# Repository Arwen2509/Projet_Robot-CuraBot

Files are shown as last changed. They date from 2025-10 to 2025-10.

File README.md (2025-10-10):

Le projet de ma première année en école d'ingénieur consistait à créer un robot autonome, donc capable d'effectuer certaines tâches seul.
Nous devions d'abord trouver un sujet, puis une problématique, et enfin nous renseigner sur les solutions existantes afin de produire la nôtre.
Ainsi l'idée nous est venue de proposer un robot autonome capable de se déplacer seul dans un hôpital pour livrer des médicaments directement aux patients dans leurs chambres.

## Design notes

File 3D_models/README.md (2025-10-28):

# 3D Models

This folder contains all 3D models for the CuraBot project.

## Description
The 3D models in this folder are used for the robot components and can be printed using a 3D printer.

## Usage
These files are ready to be used for manufacturing and assembly of the CuraBot.

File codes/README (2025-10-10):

Notre robot fonctionne à l'aide de 2 cartes Arduino, et donc de 2 codes.
Les cartes communiquent en I2C, une première permet de gérer l'écran d'affichage (maître), et la deuxième contrôle tous les autres composants, moteurs, capteurs... (esclave).

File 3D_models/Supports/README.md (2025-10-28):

# Supports

This folder contains the 3D models for support components and accessories of the CuraBot.

## Contents

The files in this directory include:
- Sensor mounts and holders
- Crazy wwheel support
## File Format

All 3D models are provided in 3mf format for 3D printing.

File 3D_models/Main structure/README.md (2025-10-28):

# Main Structure

This folder contains the 3D models for the main structural components of the CuraBot.

## Contents

The files in this directory include:
- Main chassis and frame components
- Structural support pieces
- Base plates and mounting brackets
- Core mechanical assemblies

## File Format

All 3D models are provided in STL format for 3D printing.

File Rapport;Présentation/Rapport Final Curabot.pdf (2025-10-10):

Rapport final de projet : CuraBot, le livreur de médicament

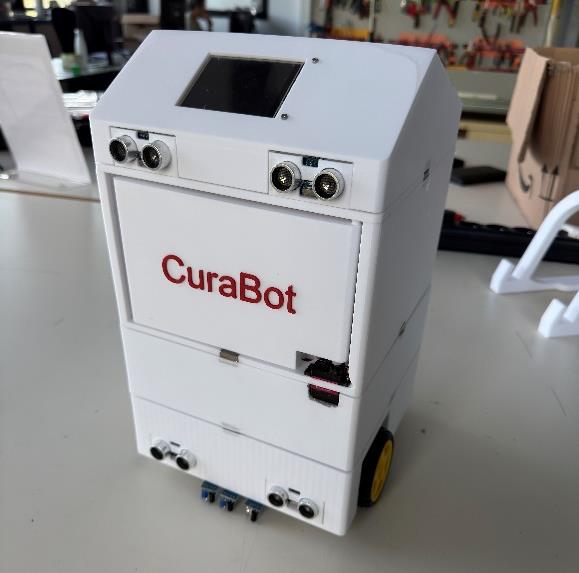
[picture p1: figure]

Table des matières

I. Introduction

Dans l’objectif de l'amélioration continue des soins hospitaliers, la gestion des tâches logistiques constitue un défi important pour les équipes soignantes, en particulier les infirmiers. Ceux-ci sont souvent confrontés à une charge de travail élevée, combinant soins aux patients, gestion des traitements et activités annexes comme la distribution de médicaments. Ce cumul de tâches, bien que nécessaire, peut entraîner une surcharge cognitive et physique, affectant la qualité des soins prodigués et le bien-être des professionnels de santé.

Ce robot a été réalisé dans le cadre du projet pédagogique de troisième année de Robotique. CuraBot est le résultat d’un travail commun en binôme, se reposant sur une répartition des tâches efficaces : la partie programmation et électronique d’une part, la conception structurelle et l’assemblage du robot de l’autre. Ce rapport met en lumière les choix techniques, les contraintes rencontrées et les solutions mises en œuvre pour le bon fonctionnement du robot.

L’objectif principal de CuraBot est de soulager le personnel hospitalier. Il doit apporter les médicaments aux patients de chambres différentes en suivant une ligne tracée au sol. Il est conçu pour qu’il soit modulaire : on doit pouvoir rajouter des baies à médicaments suivant les besoins de l’hôpital.

II. Schéma Electrique

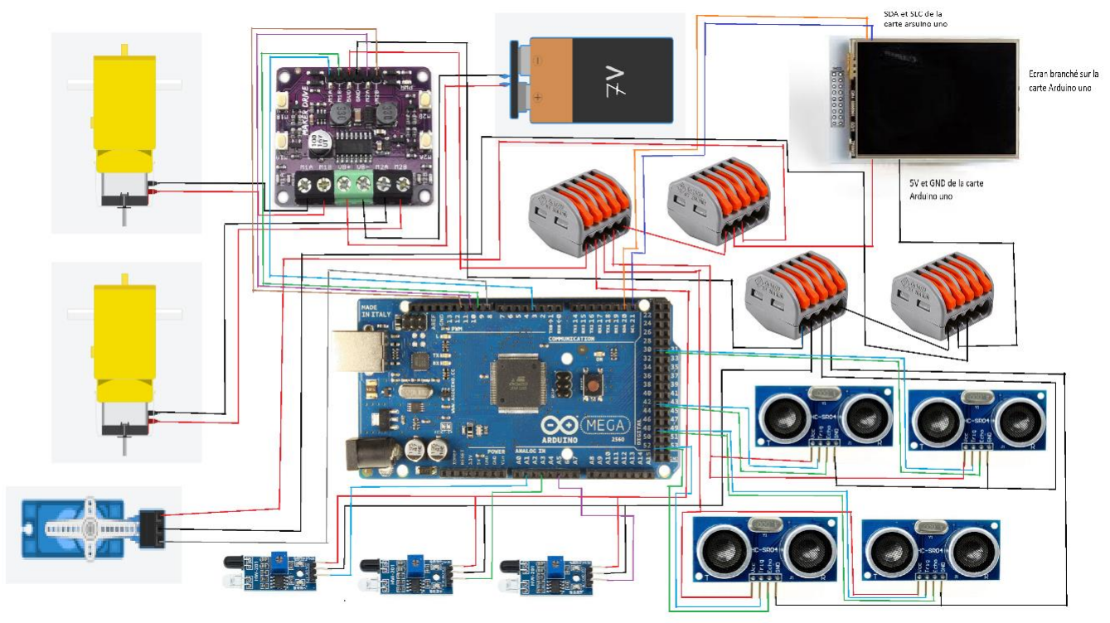
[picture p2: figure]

III. Algorithme de fonctionnement

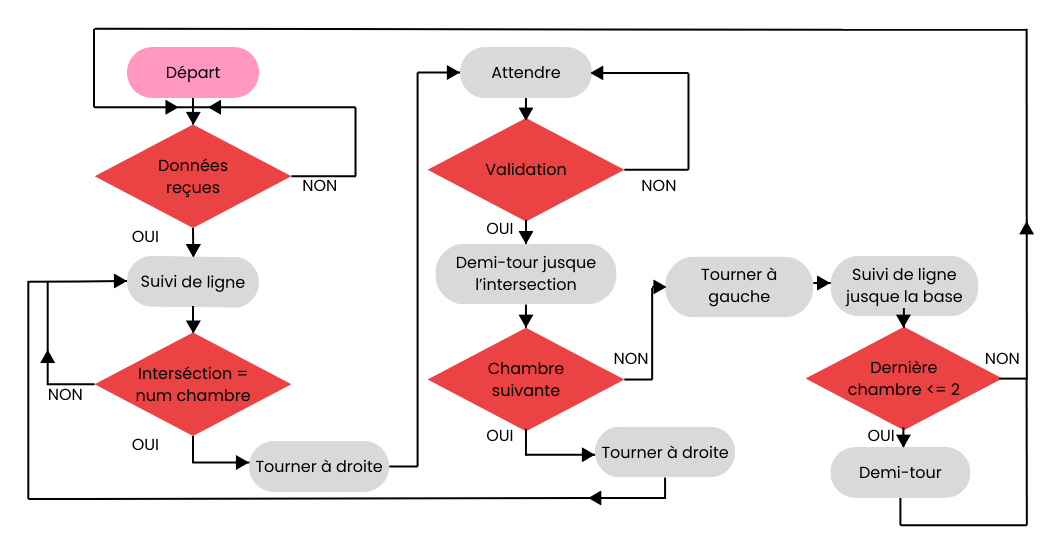
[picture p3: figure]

Pour la programmation on retrouve 3 parties principales :

Écran + Communication I2C:

L’écran sert d’interface homme-machine, il est donc programmé pour avoir une interface claire et simple d’utilisation permettant de choisir la liste des chambres que doit livrer le robot. Une fois cette liste sélectionnée l’information doit aller de l’écran connecté sur l’Arduino Uno jusqu'à la carte Arduino Mega contrôlant les moteurs et différents capteurs. Le code comporte donc une partie pour gérer la communication I2C entre les deux cartes.

Suivi de ligne :

La carte Arduino Mega est programmée pour lancer le robot une fois que celle-ci reçoit l’information provenant de l’écran. Le robot doit suivre la ligne noire jusqu’à atteindre la chambre qu’il doit livrer. Pour cela, la carte est programmée pour contrôler les moteurs en fonction des données reçues par les capteurs infrarouges. De plus pour savoir si le robot a atteint la bonne chambre ou non il compte les intersections (quand les trois capteurs IR captent la ligne).

Contrôle porte :

Une fois arrivé dans la bonne chambre, le robot ouvre la porte et attend une validation provenant de l’écran. Cette partie de code se base encore une fois sur la communication I2C entre les deux cartes pour que le robot ferme la porte une fois la validation effectuée sur l’écran.

Ensuite, le robot sort de la chambre et va à la suivante ou bien retourne à sa base de départ.

IV. | Coûts du projet
Inventaire | Nombre/Quantité Prix unitaire | | Coût total par produit
Capteur Ultra-Son | 4 | 3,49 | 13,96
3 Capteur Infra-Rouge | 1 | 6,99 | 6,99
Arduino Mega | 1 | 30,04 | 30,04
Arduino Uno | 2 | 9,99 | 19,98
Ecran LCD | 1 | 24,99 | 24,99
Servomoteur | 1 | 3,50 | 3,50
Moteur DC | 2 | 2,00 | 4,00
2 Roues | 1 | 6,39 | 6,39
Roue folle | 1 | 2,25 | 2,25
Interrupteur | 1 | 0,98 | 0,98
Batterie 7,4V | 1 | 16,98 | 16,98
Contrôleur Cytron | 1 | 5,11 | 5,11
Boîtes de 120 câbles Dupont | 1 | 8,99 | 8,99
Bobine PETG | 2 | 19,99 | 39,98
| | Total coût matériel | 184,13
Etudiant | Nombre d'heures de cours | Nombre d'heures supp | Taux horaire Brut | Coût humain
Arwen | 80 | 150 | 20,88 | 4802,4
Alexis | 80 | 210 | 20,88 | 6055,2
| | | Total | 10857,6
Total matériel | 184,13
Total humain | 10857,6
Coût Total | 11041,73
V. Ajustements bibliographie

Lors de la phase de conception initiale, nous avions envisagé d’intégrer à CuraBot un système de contrôle à distance par Bluetooth via une application mobile conçue avec AppInventor, ainsi qu’un système de localisation par lecture de QR codes placés devant les chambres. Le Bluetooth permettait théoriquement de sélectionner les chambres à livrer sans interface embarquée, tandis que les QR codes devaient permettre au robot de reconnaître précisément l’endroit où il se trouvait afin de s’arrêter devant la bonne chambre.

Cependant, ces choix ont été abandonnés au cours de l’évolution du projet. Le contrôle Bluetooth, bien que fonctionnel dans un cadre simple, s’est révélé peu robuste et peu intuitif en environnement réel. Il nécessitait une connexion stable, une application tierce à maintenir, allongeait inutilement le temps de configuration et aurait interféré avec. L’intégration d’un écran tactile s’est finalement révélée plus ergonomique, en réunissant en un seul dispositif l’affichage et la saisie des informations.

Concernant les QR codes, la reconnaissance s’est avérée plus complexe à mettre en œuvre que prévu, notamment en raison des contraintes de positionnement, de luminosité, et du traitement d’image requis. Nous avons donc choisi de nous orienter vers un système plus simple et plus robuste basé uniquement sur le suivi de ligne combiné à des repères d’intersection, assurant une meilleure régularité de fonctionnement et facilitant les tests.

VI. Problématiques surmontées
Le robot était initialement prévu pour rouler grâce à 2 roues motrices sur les deux côtés au milieu et 2 roues folles positionnées sur l’avant et l’arrière. Or ce système ne rendait finalement pas stable CuraBot. Il a donc été choisi d’enlever une roue folle pour passer sur un système de trois supports en forme de triangle : les deux roues motrices dans les coins avant et la roue folle au centre à l’arrière.

VII. Conclusion et perspective
Ce rapport bibliographique nous a permis d’explorer les différentes approches techniques envisageables pour la conception d’un robot livreur de médicaments, en confrontant nos idées initiales aux contraintes réelles de mise en œuvre. Au fil de nos recherches, nous avons pu affiner notre cahier des charges, identifier les solutions les plus adaptées à notre contexte, et proposer une première version de CuraBot reposant sur un système de suivi de ligne, à la fois simple, économique et fiable.

Nos choix ont été guidés par le souci de faisabilité dans le cadre d’un premier prototype, avec une priorité donnée à la stabilité, la modularité mécanique, et la cohérence fonctionnelle. Certains dispositifs initialement envisagés, comme le contrôle Bluetooth ou la lecture de QR codes, ont été écartés en faveur de solutions plus robustes et ergonomiques, comme l’intégration d’un écran tactile et d’un système de repérage par trajectoire prédéfinie.

Dans la continuité du projet, nous souhaitons faire évoluer CuraBot vers une version plus autonome et intelligente. Pour cela, l’objectif principal de l’année prochaine est de remplacer le système de suivi de ligne par une navigation basée sur la cartographie 3D de l’environnement, rendue possible grâce à l’intégration d’un capteur LiDAR.

Cette technologie permettra à CuraBot :

- De construire une carte de son environnement en temps réel (SLAM),
- De naviguer librement dans des couloirs sans balisage au sol,
- D’éviter dynamiquement les obstacles même imprévus (chariots, personnes),
- Et d’atteindre une flexibilité d’usage bien plus proche des standards industriels des robots hospitaliers actuels.

Cette prochaine étape nécessitera une refonte partielle de l’architecture logicielle du robot, un traitement de données plus complexe, ainsi qu’une amélioration de la capacité de calcul embarquée. Elle représente un véritable défi technique, mais aussi une opportunité d’approfondir nos compétences en robotique mobile, en intelligence embarquée et en algorithmique de navigation.

En résumé, ce projet nous a permis de poser des bases solides sur le plan technique et organisationnel, que nous comptons enrichir l’année prochaine pour franchir une nouvelle étape vers un robot plus autonome, intelligent et adapté aux besoins réels des hôpitaux modernes.

VIII. Bibliographie
Liens matériels :

120 Câbles Dupont (https://www.amazon.fr/AZDelivery-Jumper-Cavalier-C%C3%A2ble-Arduino/dp/B074P726ZR) - Bobine PETG (https://www.amazon.fr/eSUN-Pr%C3%A9cision-Dimensionnelle-Cartouche-Imprimante/dp/B07FXGXFH3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) -Controleur Cytron (https://eu.robotshop.com/fr/products/controleur-moteur-h-bridge-pour-debutant-maker-drive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) - Batterie 7,4V (https://www.amazon.fr/Batteries-Rechargeables-connecteur-l%C3%A9lectronique-%C3%A9quipement/dp/B0BQGSKGTK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) - Interrupteur (https://www.amazon.fr/GTIWUNG-Interrupteur-Commutateur-poussoir-appareils/dp/B08CY5437N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) - Roue Folle (https://www.amazon.fr/Roulettes-Demenagement-Pivotantes-Auto-adh%C3%A9sives-Universelles/dp/B0DQYFWRXQ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) - 2 Roues (https://www.amazon.fr/Baosity-Intelligent-Voitures-Arduino-Bricolage/dp/B07QL3CDTW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) - Moteur DC (https://www.amazon.fr/Vitesses-Engrenages-Voiture-Intelligent-Arduino/dp/B096ZH5WQ6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) - Servomoteur (https://www.amazon.fr/Binghe-Servomoteur-Rotation-h%C3%A9licopt%C3%A8re-Compatible/dp/B0DFCGD34B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) - Ecran LCD Tactile (https://www.amazon.fr/ELEGOO-Tactile-320x240-Technical-Arduino/dp/B01JD4TJZU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) - Arduino Uno (https://www.amazon.fr/ElectroWorldFR-Controller-ATmega328P-Microcontr%C3%B4leur-Compatible/dp/B0BVGW4SC8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) - Arduino Mega (https://www.amazon.fr/Retoo-Atmega-Microcontr%C3%B4leur-Board-microcontr%C3%B4leur/dp/B0BY8R9Y7N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) - 3 Capteurs Infra-Rouge (https://www.amazon.fr/AZDelivery-infrarouge-kollissions-d%C3%A9tection-obstacles/dp/B07D924JHT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) - Capteur Ultra Son (https://www.amazon.fr/OcioDual-Ultrasons-T%C3%A9l%C3%A9m%C3%A8tre-Ultrasonique-Raspberry/dp/B075MDMDL2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)

Liens aide au développement :

https://www.aranacorp.com/fr/utilisation-dun-shield-tft-lcd-avec-arduino/

https://circuitdigest.com/microcontroller-projects/arduino-i2c-tutorial-communication-between-two-arduino (https://circuitdigest.com/microcontroller-projects/arduino-i2c-tutorial-communication-between-two-arduino)

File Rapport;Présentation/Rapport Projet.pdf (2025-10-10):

# RAPPORT BIBLIOGRAPHIQUE

## Année scolaire 2024-2025

# "CuraBot, le livreur de médicament"

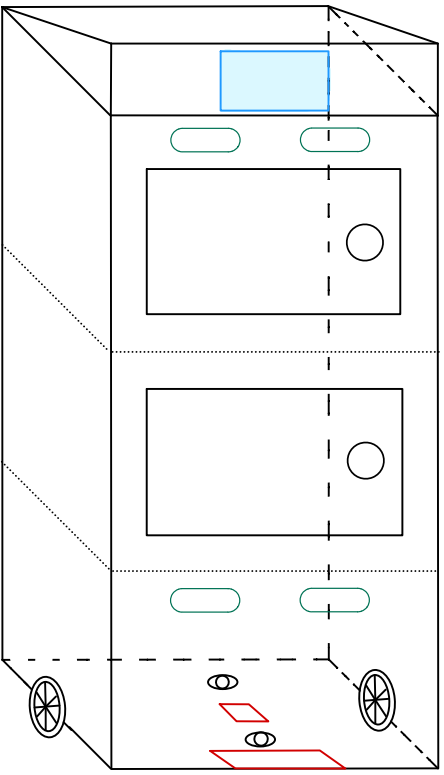
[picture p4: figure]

# Etudiants : Arwen Fracassi, Alexis Xueref Encadrant : Pascal Masson

Ecole Polytechnique Universitaire de Nice Sophia-Antipolis, Robotique Systèmes Autonomes930 route des Colles, Parc de Sophia Antipolis, 06410 BIOT

Université Cote d’Azur

## Sommaire

# Introduction

Dans l’objectif de l'amélioration continue des soins hospitaliers, la gestion des tâches logistiques constitue un défi important pour les équipes soignantes, en particulier les infirmiers. Ceux-ci sont souvent confrontés à une charge de travail élevée [1], combinant soins aux patients, gestion des traitements et activités annexes comme la distribution de médicaments. Ce cumul de tâches, bien que nécessaire, peut entraîner une surcharge cognitive et physique, affectant la qualité des soins prodigués et le bien-être des professionnels de santé.

Face à ces enjeux, l’automatisation des tâches répétitives et non directement liées aux soins, telle que la livraison des médicaments, apparaît comme une solution innovante pour alléger la charge de travail des infirmiers. C’est dans cette optique que l’idée d’un robot livreur de médicaments au sein des hôpitaux a émergé. En développant un système robotisé capable de transporter et distribuer les médicaments aux différents services, il serait possible de libérer du temps pour les infirmiers [2], leur permettant ainsi de se concentrer sur leurs fonctions principales : l'accompagnement et les soins des patients.

Ce rapport bibliographique a pour objectif d’explorer les différentes technologies existantes dans le domaine de la robotique hospitalière, d’analyser les systèmes similaires déjà en place et d’évaluer leur pertinence pour la conception d’un robot livreur de médicaments à tous les niveaux de conception du robot.

# Chapitre I : Présentation générale du robot

Les robots de livraison de médicaments se répartissent majoritairement en deux types : ceux qui se déplacent de manière autonome en s'adaptant à l'environnement de l'hôpital, et ceux qui suivent des parcours prédéfinis, comme des lignes tracées au sol.
Même si les robots autonomes, avec leurs capteurs comme le LIDAR ou des caméras, semblent plus flexibles puisqu'ils peuvent réagir aux changements autour d’eux, ils présentent des inconvénients. Ils sont plus chers à fabriquer, leur entretien est plus complexe, et ils demandent une infrastructure technologique plus poussée. Dans un hôpital, où les itinéraires sont souvent réguliers et prévisibles, cette flexibilité n’est pas aussi critique. Notre plus grande inspiration étant le REEMAN Drug Delivery [3] utilisant ce système. Il représentait la vision du robot livreur que l’on avait. Or nous avons décidé de ne pas partir sur la cartographie car c’est une technique plus complexe et demandant en ressources.
C’est pourquoi, pour une solution plus simple et efficace, nous allons privilégier les robots suiveurs de ligne [4]. Ces robots utilisent des capteurs optiques pour suivre une ligne tracée au sol, ce qui permet de naviguer précisément avec un système facile à installer et à maintenir. En plus, ce type de robot coûte moins cher que les modèles autonomes, et les tracés au sol peuvent être rapidement ajustés si jamais il faut changer un itinéraire, ce qui offre quand même une bonne flexibilité pour les besoins de l’hôpital.
Nous prévoyons aussi de rendre notre CuraBot modulaire, en offrant la possibilité d’augmenter la capacité de livraison, améliorant ainsi l'efficacité en réduisant le nombre de trajets nécessaires. Mais aussi de proposer une flexibilité aux hôpitaux d’adapter le robot à des besoins variables en permettant une réduction des coûts.
En résumé, CuraBot, le robot modulaire suiveur de ligne est une solution pratique, économique, et bien adaptée afin de gérer la logistique dans un hôpital.

# Chapitre II : Design

## II.1. Cahier des charges

Nous souhaitons que le robot soit modulaire, donc qu’il permette d’ajouter ou de retirer des étages facilement, sans nécessiter d’outils complexes. Chaque étage doit pouvoir transporter un certain nombre de médicaments dans des compartiments sécurisés. CuraBot doit pouvoir suivre des lignes tracées au sol via des capteurs adaptés, même avec plusieurs étages ajoutés.

## II. 2. Structures envisagées

### II. 2. 1. Le robot pilule

Initialement, nous avons imaginé de modéliser notre robot en forme de pilule de médicament comme le montre la Figure 1. Afin de faire un rappel avec l’objet de nos livraisons. Cependant, nous nous sommes heurtés rapidement avec des contraintes techniques qui auraient empêché de positionner les roues sur la face du bas aisément, notamment les roues folles, qui permettent la stabilisation du robot. De plus, l’intégration des capteurs sur la surface arrondie peut compliquer leur orientation et la précision de leurs mesures. La fabrication et l’assemblage d’une forme arrondie est plus complexe qu’une forme avec des bords plats.

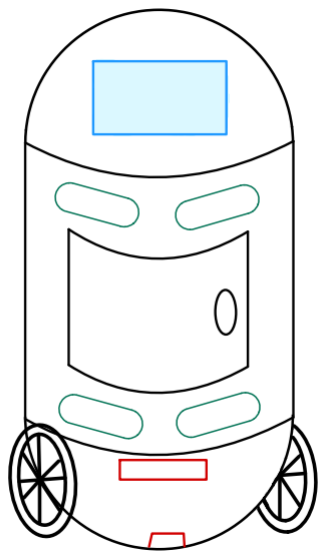
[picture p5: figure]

Figure 1 : Schéma du robot pilule

### II. 2. 2. Le REEMAN Drug Delivery Intelligent Robot

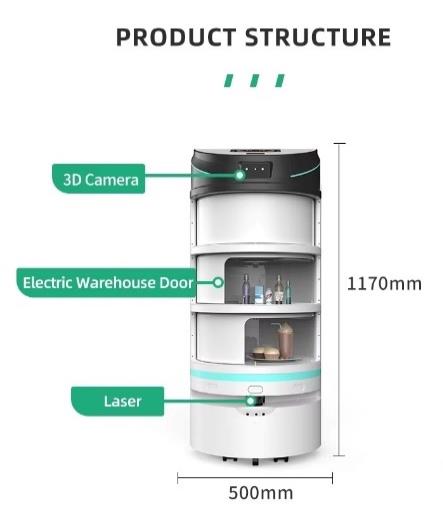
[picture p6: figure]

Notre étude s’est portée par la suite sur Le
REEMAN Drug Delivery Intelligent Robot [3] (figure 2) dont la forme était toujours arrondie mais avait une surface plane au niveau de la base afin de pouvoir disposer les roues et capteurs suiveur de lignes facilement et proche du sol. Néanmoins, ce robot n’utilise pas un système de suivi de ligne mais un système de caméra et laser, ce qui n’est pas dans la ligne directrice de notre robot. De surcroît, nous cherchons à ce que l’ouverture des portes se fasse de façon battante et pas coulissante, ce qui n’est pas prévu par ce robot. La forme arrondie n’est pas optimale pour l’installation des capteurs d’obstacle et pour la fabrication du robot. Enfin, ce robot n’est pas modulaire, on ne peut pas choisir d’enlever ou de rajouter des étages.

## II. 3. Structure retenue

À la suite de nos recherches, nous avons décidé de partir sur un robot en forme de parallélépipède rectangle. En effet cette forme va nous permettre de pouvoir facilement positionner les roues et calibrer les capteurs nécessaires au suivi de ligne et de détection d’obstacle comme le montre la figure 3. D’autre part, avoir des faces planes nous permet d’avoir une ouverture pour les portes de type battante sans gênes au niveau du pivot.
Concernant la partie modulaire, notre choix s’est porté sur le fait de séparer en blocs notre robot. En effet, nous l’avons découpé en 3 modules différents :
- Le module Motorisation : Ce module va être composé de toute la partie basse du robot. On va y retrouver les différentes roues, les moteurs pour faire tourner les roues, les capteurs de suivi de lignes, le capteur de QR-code, les cartes électroniques qui feront fonctionner le robot et toute l’électronique qui permettra de se relier aux autres blocs. Il sera le plus lourd car la plus grande partie des composants y sera mais aussi pour s’assurer que la structure ne bascule pas lors de déplacements.
- Le module Interface : Ce module est celui qui rend possible l’interaction Homme-Machine. En effet, ce sera sur ce module que nous allons retrouver l’écran qui offrira la possibilité de choisir le trajet du robot. On retrouvera aussi deux capteurs à obstacles, qui servent à détecter les obstacles en hauteur. Mais aussi, un compartiment de livraison de médicament, où un moteur permettant de contrôler la porte sera présent.

Figure 2 : Le REEMAN Drug Delivery Intelligent Robot

- Le module Médicament : Ce module est celui qui offrira la possibilité d’augmenter la capacité du robot. En effet, seul ce module peut être rajouté et ne comporte aucuns composants essentiels au fonctionnement du robot. On y retrouvera seulement la baie à médicaments et le moteur permettant d’ouvrir et de refermer la porte.

Le robot doit avoir obligatoirement le module Motorisation et Interface pour fonctionner correctement, il ne pourra pas faire sans. C’est pour cela que nous avons choisi d’inclure une baie à médicaments dans le module Interface. Les modules seront tous modélisées de façon qu’ils s’emboîtent entre eux avec des zones de fixations à vis pour être sûr qu’ils ne se désolidarisent pas du robot. La partie du fond du robot sera creuse afin de faire passer tous les câbles plus facilement.

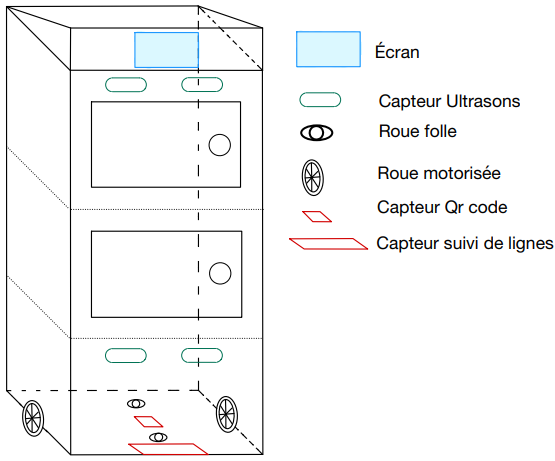
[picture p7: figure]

Figure 3 : Schéma de CuraBot

# Chapitre III : Déplacements et repères

## III.1. Cahier des charges

Notre robot doit livrer des médicaments à des endroits précis, pour cela il doit être capable de se déplacer et se repérer correctement dans son environnement, tout en étant capable de s’arrêter aux endroits indiqués.

## III. 2. Déplacement dans l’environnement

Le robot peut se déplacer dans un certain lieu de différentes manières, il peut soit connaitre le lieu par cartographie, soit savoir où il doit se rendre en suivant une ligne par exemple.
Dans la première option on retrouve la cartographie [5] par laser, présente dans certains aspirateurs robots qui leur permet de détecter des obstacles et de connaitre la distance à laquelle ils se trouvent afin de faire une carte de la pièce. Cependant cela nécessite que le robot se déplace dans tout son environnement une première fois juste pour le découvrir.
Il existe aussi la cartographie par camera, mais cette solution est bien plus couteuse et plus complexe.
C’est pourquoi nous avons décidé de nous tourner vers un robot suiveur de ligne [4], celui-ci étant plus simple à réaliser et tout aussi efficace dans notre cas. Le robot connait précisément son trajet plutôt que l’entièreté de son environnement, et il en va de même pour le personnel qui peut donc prévoir comment va se déplacer le robot.

## III. 3. Arrêts

Le robot doit être capable de s’arrêter au bon endroit, il doit s’arrêter aux chambres indiquées afin d’y livrer les médicaments. Pour cela nous avons parcouru plusieurs possibilités. La première consistait à utiliser le nombre d’intersections rencontrées par le robot pour qu’il “connaisse” le numéro des chambres à sa gauche et à sa droite et qu’il choisisse son chemin en fonction.

Mais nous avons finalement opté pour un scan de QR code (cf annexe 1). Les QR codes seront disposés sur le trajet du robot face à la chambre correspondante comme le montre la figure 4, le robot pourra donc suivre son trajet tout en les scannant et ainsi s’arrêter lorsqu’il se trouvera devant la bonne chambre. Afin d’accéder à la chambre le robot devra aussi attendre que la porte soit bien ouverte.

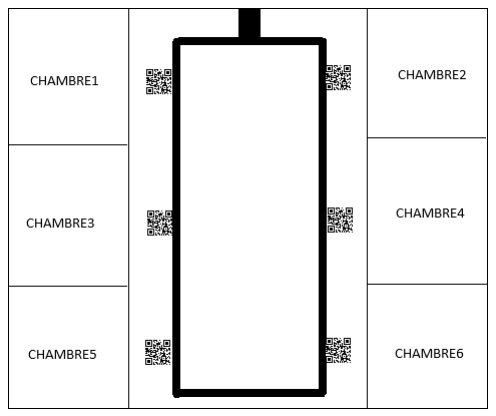
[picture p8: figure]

Figure 4 : Chemin du CuraBot

## III. 4. Roues

Nous nous sommes ensuite intéressés au choix des roues. On s’est d’abord penchés sur les roues des aspirateurs robots Roomba [6] car celles-ci sont proches du sol comme notre robot. Ces roues permettent au robot de passer sur certains obstacles au sol comme les tapis. Pour notre projet, le robot circule dans un hôpital, et donc il ne devrait pas rencontrer d’obstacles de ce genre, ce type de roue n’est donc pas nécessaire.
Nous nous sommes ensuite renseignés sur les roues Omniwheel [7], celles-ci permettent au robot de tourner dans toutes les directions. De même que pour les roues de Roomba cela n’est pas nécessaire dans notre cas.
Finalement l’utilisation de deux roues simples (cf annexe 1) motorisées ainsi que deux roues folles (cf annexe 1) nous a parue être la meilleure option. Les deux roues motorisées sur les côtés du robot lui permettront de tourner afin de suivre correctement son trajet, et les roues folles permettrons de rajouter de l’équilibre au robot.

# Chapitre IV : Motorisation

## IV. 1. Cahier des charges

Le robot doit être capable d’avancer en supportant sa propre masse et celles des médicaments. Il doit aussi pouvoir tourner sur lui-même et pouvoir ouvrir et refermer les portes des baies à médicaments.

## IV. 2. Motorisation des roues

Afin de répondre aux exigences du cahier des charges, nous avons décidé de partir sur deux moteurs avec encodeur et un contrôleur. En effet, cette configuration va nous permettre de contrôler chaque roue du robot.
Les moteurs de 6V, choisis pour leur efficacité énergétique, offrent une puissance suffisante pour propulser le robot et transporter une charge légère à modérée, comme celle des médicaments. Ces moteurs, tout en étant peu gourmands en énergie, sont capables de fournir la force nécessaire pour déplacer le robot de manière fluide, même lorsqu’il est chargé. Cela garantit que le robot pourra avancer sans difficulté, supportant à la fois son propre poids et celui de sa cargaison.
Le contrôleur Cytron, associé à cette configuration, permet de réguler précisément la vitesse et la direction des roues. Grâce à la modulation de largeur d’impulsion (PWM), il est possible d'ajuster le fonctionnement de chaque moteur indépendamment, ce qui permet au robot de réaliser des manœuvres complexes telles que des virages serrés ou des rotations sur place. La capacité de tourner sur lui-même est ainsi assurée par la possibilité de contrôler individuellement chaque roue. En faisant tourner les roues dans des directions opposées, le robot peut pivoter sur lui-même, répondant ainsi à cette exigence du cahier des charges. L’intégration d’encodeurs sur les moteurs Cytron apporte un avantage supplémentaire en termes de contrôle. Les encodeurs permettent de mesurer avec précision la rotation des roues, offrant un retour d’information en temps réel sur la position et la vitesse. Cela permet de corriger les déviations éventuelles, assurant ainsi que le robot suit sa trajectoire avec précision, même en cas de changements de charge ou de surface. Ce retour d'information est essentiel pour maintenir un suivi optimal de la ligne tracée au sol et garantir que le robot reste sur sa route prévue.
Ainsi, la solution proposée, avec deux moteurs de 6V et un contrôleur Cytron, répond pleinement aux critères du cahier des charges en assurant que le robot peut avancer tout en supportant sa charge et effectuer des rotations sur lui-même, tout en restant fiable et économe en énergie. (cf annexe 1 pour toutes les pièces)

## IV. 3. Motorisation des portes

Afin de contrôler l’ouverture des portes, nous nous sommes retrouvés face à la problématique de pouvoir ouvrir la porte manuellement et que CuraBot prenne en compte cette ouverture afin qu’il adapte la rotation nécessaire pour la fermeture.
Le servomoteur paraît être le meilleur choix car il offre la possibilité de suivre la position de la porte et même d’ajuster sa position par la suite. Mais, un servomoteur standard peut être gênant pour une ouverture manuelle, car il impose sa position. Cependant, il existe des servomoteurs avec retour de position ou des mécanismes d’embrayage qui désengagent le moteur quand la porte est ouverte manuellement (cf annexe 1).

# Chapitre V : Capteurs

## V.1. Cahier des charges

Dans notre projet nous avons besoin de capteurs pour deux raisons principales, d’abord pour permettre au robot d’effectuer le suivi de ligne, et ensuite pour détecter des obstacles potentiels sur son chemin.

## V.2. Suivi de ligne

Pour se déplacer, le robot devra suivre une ligne noire au sol, pour cela nous allons utiliser trois capteurs infrarouges disposés de la même façon que sur la figure 5 (cf annexe 1).

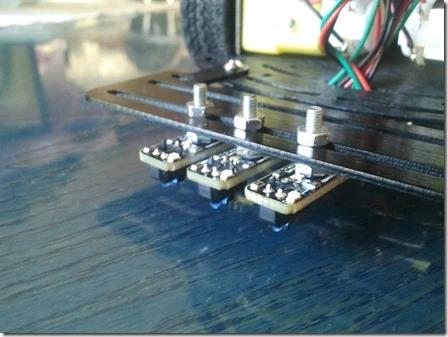
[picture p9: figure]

Figure 5 : Capteurs suivi de lignes

Les trois capteurs permettront au robot de savoir s'il est sur le bonne trajectoire ou non. Le capteur du milieu est sensé rester au-dessus de la ligne noire et donc ce capteur ne doit pas recevoir de lumière, contrairement aux deux capteurs sur les côtes. De ce fait, si l’un des deux autres capteurs ne reçoit plus la lumière, cela signifie que le robot doit modifier sa trajectoire.

## V.3. Détecter les obstacles

Comme nous nous sommes intéressés au fonctionnement des robots aspirateur nous avons aussi observé les capteurs qu’ils utilisaient.
Certains modèles utilisent des capteurs de contact afin de changer de direction lorsqu’ils touchent un obstacle. Cependant ce type de capteurs ne correspond pas à notre projet, on veut que le robot détecte les obstacles pour s’arrêter avant de les atteindre, et les contourner si nécessaire.

On retrouve aussi l’utilisation du lidar [8], celui-ci utilise des lasers infrarouges afin de détecter tous les obstacles autour de lui et mesurer à quelles distances ils se trouvent. Bien que ce système fonctionne très bien et permette d’obtenir beaucoup de données, la plupart ne nous seront pas utiles, l’utilisation de ce capteur n’est donc pas nécessaire.

Ensuite, la détection d’obstacle est aussi possible grâce à des capteurs infrarouge, cependant le laser risque de passer au travers de surfaces vitrés et donc ne pas renvoyer les bonnes informations au robot.

Finalement, nous avons décidé d’utiliser des capteurs à ultrason (cf annexe 1), étant simples à utiliser et permettant de détecter des obstacles à une distance raisonnable. Ainsi lorsque le capteur détecte un obstacle le robot doit s’arrêter, et si l’obstacle est toujours présent ou bout d’un certain temps celui-ci devra le contourner.

# Chapitre VI : Interface Homme-Robot

## VI.1. Cahier des charges

Dans notre cas, le robot doit interagir avec l’utilisateur, afin de savoir à quelles chambres il doit se rendre. Mais celui-ci pourra aussi afficher des informations pour les autres membres du personnel qu’il pourrait croiser ainsi que pour les patients.

## VI.2. Solutions étudiées

Pour sélectionner les chambres à livrer un Numpad serait suffisant, cependant ce système ne nous permettrait pas d’obtenir d’autres informations, comme un affichage des chambres qu’il va livrer pour vérifier qu’une erreur n’a pas été faite.

Au contraire un simple écran non tactile permettrait l’affichage d’information mais on ne pourrait pas choisir directement les chambres à livrer depuis le robot. Ce type de modèle pourraient convenir s’il était combiné à l’utilisation d’une application mobile permettant de communiquer par Bluetooth avec le robot comme AppInventor MIT. Dans ce cas la communication Bluetooth permettrait de transmettre le numéro des chambres à livrer et l’écran permettrait d’afficher certaines informations.
Il nous parait donc plus simple d’utiliser directement un écran tactile Module d’affichage LCD , il permettrait de réunir les deux fonctions en même temps (cf annexe 1). L’utilisation du fonctionnement en Bluetooth peut toujours être utile pour le contrôler sans avoir à être à côté de lui.

# Chapitre VII : Alimentation et Matériaux

## VII. 1. Alimentation

Voici un récapitulatif de tout ce qui doit être alimenté dans le robot avec leur tension nominale :
- 2 moteurs DC avec encodeur FIT0450 : 6V.
- 1 Servomoteur SG90 : 4,8V ~ 6V.
- 1 Contrôleur Cytron : 7V.
- Écran tactile LCD : 3.3V ~ 5V.
- Carte Arduino Méga : +5V.
- Capteurs

Nous choisissons une batterie 7,4V pour s’assurer que chaque composant ne soit pas sous-alimenté. Nous décidons tout de même d’utiliser un régulateur de tension jusqu’à 6V pour être sûr de ne pas endommager les éléments. Afin de ne pas rendre le robot trop lourd, et ainsi le rendre le plus efficient possible, la batterie devra être petite et légère (cf annexe 1).

## VII. 2. Matériaux

Notre robot ne doit être trop lourd afin que les moteurs puissent supporter son poids. Or, il doit tout de même être assez solide pour qu’il ne vacille pas lors de ses déplacements. C’est pour cela que toute la partie motorisation se situe au niveau du bas, afin que la base soit solide. Pour la structure, nous envisageons en première étape d’utiliser du bois découpé au laser afin de faire des ajustements facilement. Lorsque tous les ajustements et positionnements des pièces seront faits, nous passerons à l’impressions 3D en plastique, afin que le robot soit plus esthétique et qu’il corresponde visuellement à note idée de départ.
Il nous parait donc plus simple d’utiliser directement un écran tactile Module d’affichage LCD série SPI, il permettrait de réunir les deux fonctions en même temps (cf annexe 1). L’utilisation du fonctionnement en Bluetooth peut toujours être utile pour le contrôler sans avoir à être à côté de lui.

# Conclusion

Le robot sera constitué de trois parties, premièrement le module motorisation, comportant l’écran tactile, une première porte motorisée par un servomoteur pour stocker des médicaments et deux capteurs à ultrason pour détecter les éventuels obstacles. Puis le module médicament étant lui constitué d’une simple porte motorisée. Et enfin le module motorisation auquel seront fixées les deux roues motorisées afin que les deux roues folles. Il comportera les moteurs DC alimentant les roues ainsi que la batterie. On y retrouvera aussi deux capteurs ultrason, les capteurs infrarouges pour le suivi de ligne ainsi que le lecteur de QR-code.

# Annexe 1 : Liste des pièces à commander

Matériel | Quantité | Lien
Ecran tactile | 1 | Lien écran tactile (https://fr.aliexpress.com/item/33060806447.html?src=google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)
Capteur ultrason | 4 | Lien capteur ultrason (https://www.amazon.fr/AZDelivery-HC-SR04-Ultrasons-T%C3%A9l%C3%A9m%C3%A8tre-Raspberry/dp/B07TKVPPHF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)
Capteur suivi de ligne | 3 | Lien suivi de ligne (https://fr.aliexpress.com/item/1005006269136211.html?src=google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)
Capteur QR-Code | 1 | Lien QR-Code (https://www.gotronic.fr/art-lecteur-de-qr-code-sen0486-34640.htm)
Module Bluetooth | 1 | Lien module Bluetooth (https://www.amazon.fr/AZDelivery-%C3%89metteur-R%C3%A9cepteur-Bluetooth-Compatible-Raspberry/dp/B0722MD4FY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)
Roue motrice | 2 | Lien roue motrice (https://www.amazon.fr/Baosity-Intelligent-Voitures-Arduino-Bricolage/dp/B07QL3CDTW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)
Roue folle | 2 | Lien roues folles (https://www.amazon.fr/Herenear-Roulettes-pivotantes-Caoutchouc-Capacit%C3%A9/dp/B06XFDBCHT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)
Batterie | 1 | Lien batterie (https://www.amazon.fr/Batteries-Rechargeables-connecteur-l%C3%A9lectronique-%C3%A9quipement/dp/B0BQGSKGTK)
Scotch noir | 1 | Lien scotch noir (https://www.castorama.fr/toile-de-reparation-scotch-ultra-noir-48mm-x-10-m/4064035009540_CAFR.prd)
Moteur roue | 2 | Lien moteur roue (https://www.amazon.fr/gp/aw/d/B096ZHKTLW/?aaxitk=13640b74a7744c27a7ef2f08cfdd1b7a&hsa_cr_id=0)
Servomoteur porte | 1 | Lien Servomoteur (https://www.amazon.fr/Fasizi-servo-engrenages-analogiques-h%C3%A9licopt%C3%A8re/dp/B09Z28X9RL)
Contrôleur Cytron | 1 | Lien contrôleur Cytron (https://www.gotronic.fr/art-shield-moteur-cc-10-a-sh-md10-37252.htm)
Régulateur de tension | 1 | Lien régulateur de tension (https://www.amazon.fr/DollaTek-AMS1117-5-5V-R%C3%A9gulateur-dalimentation-4-75V-12V/dp/B07PPKR4HW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)

# Annexe 2 : Planning de travail

Planning Arwen
Lettre | Tâches | Temps | Dépendance
A | Faire les QR codes et préparer le trajet en scotch | 2h | /
B | Montage des roues sur les moteurs | 2h | N
C | Montage capteur infrarouge et programmation du suivi de ligne | 3h | N
D | Montage lecteur QR-code et programmation lecture QR-codes | 3h | N
E | Montage, programmation capteurs ultrasons | 3h | N
F | Programmation évitement d’obstacle | 3h | /
G | Montage, programmation avec un Numpad | 4h | N
H | Test suivi de ligne et rectification si erreurs | 2h | N, A, B, C
I | Montage moteur, encodeur, contrôleur | 2h | N
K | Montage batterie, régulateur | 2h | N

Planning Alexis
Lettre | Tâches | Temps | Dépendance
L | Modélisation Prototypage | 3h | /
M | Prototypage découpe laser | 3h | M
N | Assemblage prototypage | 3h | N
O | Programmation Application Interface | 3h | /
P | Montage Ecran Interface | 2h | O
Q | Modélisation module Motorisation | 4h | /
R | Modélisation module Interface | 4h | /
S | Modélisation module Médicament | 4h | /
T | Modélisation Portes | 2h | R, S
U | Modélisation emboîtement modules | 2h | R, S, T

# Bibliographie

[6] BUT IROBOT Roue Gauche 4624872 Pour Entretien Des Sols [En ligne] // BUT. -https://www.but.fr/produits/5060359287694/Roue-Gauche-4624872-Pour-Entretien-Des-Sols.html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.
[1] Caducee.net Hôpital en crise : les infirmières réclament un plan d'urgence [En ligne] // Caducee.net. - 7 Août 2024. - https://www.caducee.net/actualite-medicale/16388/hopital-encrise-les-infirmieres-reclament-un-plan-d-urgence.html.
[2] Enora SEGUILLON Philippe LAURENSON VIDÉO. À l’hôpital d’Aix, un robot livreur de médicaments [En ligne] // La Provence. - 4 Août 2023. -https://www.laprovence.com/article/region/3572694153676614/a-l-hopital-d-aix-un-robotlivreur-de-medicaments.
itechnofrance Robot 2WD en tant que suiveur de ligne [En ligne] // itechnofrance. - 14 Mars 2013. - https://itechnofrance.wordpress.com/2013/03/14/robot-2wd-en-tant-que-suiveur-deligne/.
[3] Reeman Reeman Delivery Robot [En ligne] // Reemanrobot. -https://www.reemanrobot.com/news/delivery-robots-for-hospitals-a-new-type-of-s-66891554.html.
Robotique.tech Système de détection des obstacles avec Arduino [En ligne] // Robotique.tech. - 21 Juillet 2020. - https://www.robotique.tech/tutoriel/systeme-de-detectiondes-obstacles-avec-arduino/.
[8] SICK Capteurs LiDAR : définition, technologie, applications et solutions SICK [En ligne] // SICK. - 19 Septembre 2022. - https://www.sick.com/fr/fr/sick-sensor-blog/capteurs-lidardefinition-technologie-applications-et-solutions-sick/w/blog-capteurs-LiDAR/.Taufiq_Sobar Arduino Line Follower Uses a 4x4 Keypad [En ligne] // AutoDesk Instructables. -https://www.instructables.com/Arduino-Line-Follower-Uses-a-4x4-Keypad/.
Weiner Stacy Robots make the rounds [En ligne] // AAMC. - 12 Juillet 2019. -https://www.aamc.org/news/robots-make-rounds.
[4] Wikipédia Robot suiveur de ligne [En ligne] // Wikipédia. - 2 Avril 2024. -https://fr.wikipedia.org/wiki/Robot_suiveur_de_ligne.
[5] Wikipédia Robotic mapping [En ligne] // Wikipédia. - 22 Juillet 2023. -https://en.wikipedia.org/wiki/Robotic_mapping.
[7] Wikipédia Roue omnidirectionnelle [En ligne] // Wikipédia. - 7 Août 2024. - https://en-mwikipediaorg.translate.goog/wiki/Omni_wheel?_x_tr_sl=en&_x_tr_tl=fr&_x_tr_hl=fr&_x_tr_pto=rq. Xukyo Un robot qui détecte et évite les obstacles [En ligne] // aranacorp.com. - 9 Novembre 2018. - https://www.aranacorp.com/fr/un-robot-qui-detecte-et-evite-les-obstacles/.

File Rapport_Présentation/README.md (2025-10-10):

Pour commencer notre projet, il fallait d'abord faire des recherches ainsi qu'un rapport pour expliquer ce que l'on prévoyait de faire.
(cf Rapport Projet)

Puis, à la fin de notre projet, une présentation (cf Présentation finale CuraBot) et un rapport pour conclure sur notre projet 
(cf Rapport final Curabot) étaient demandés.

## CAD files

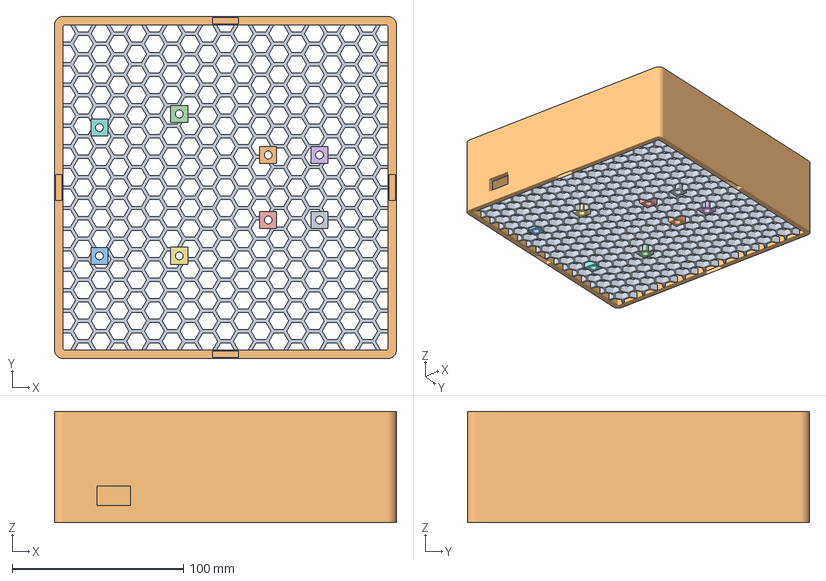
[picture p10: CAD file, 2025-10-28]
3D_models/Main structure/Elec section.3mf
200.0 x 200.0 x 65.0 mm
Corps10
Corps11
Corps12
Corps13
Corps14
Corps7
Corps8
Corps9
Hex Grid
Murs

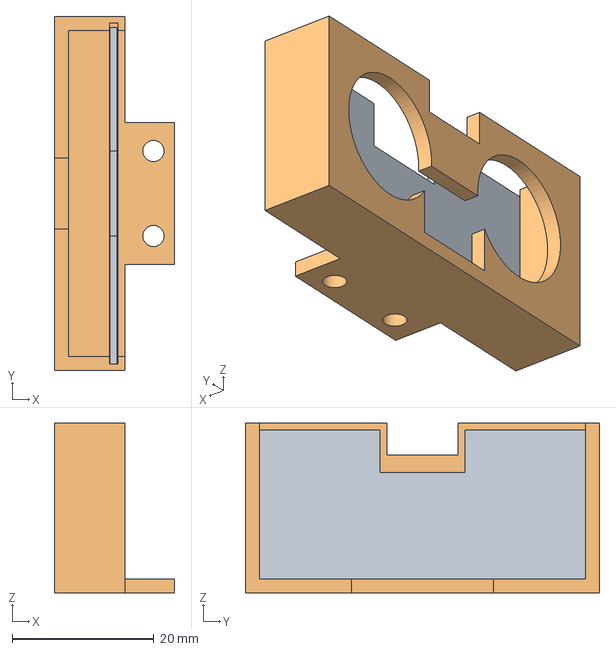
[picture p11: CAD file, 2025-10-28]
3D_models/Supports/Support Ultrasound sensor.3mf
17.0 x 50.0 x 24.0 mm
Corps1 x 2

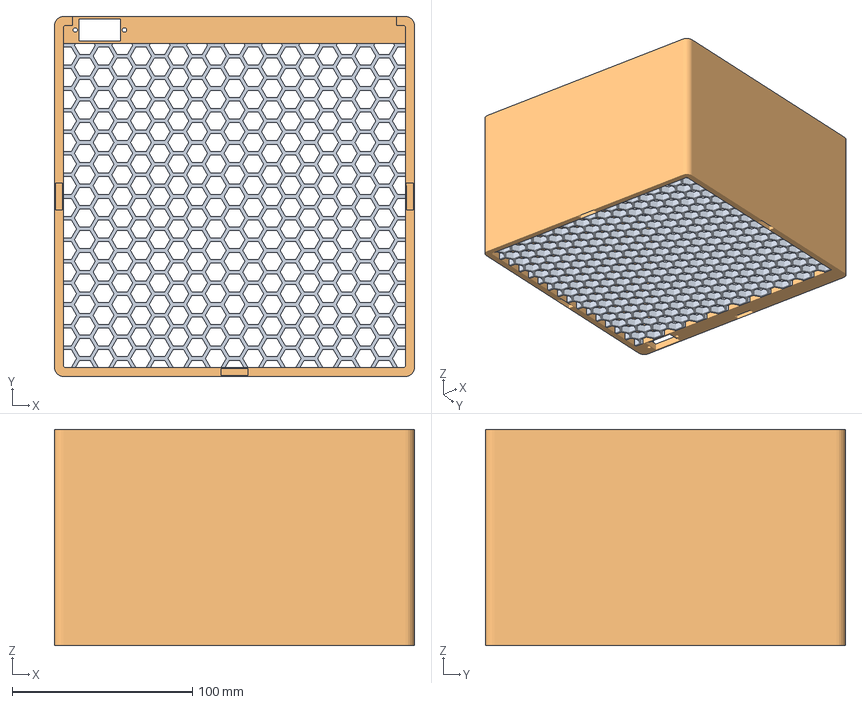
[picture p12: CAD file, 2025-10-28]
3D_models/Main structure/Medicine section.3mf
200.0 x 200.0 x 120.0 mm
Grid hex
Murs-servo

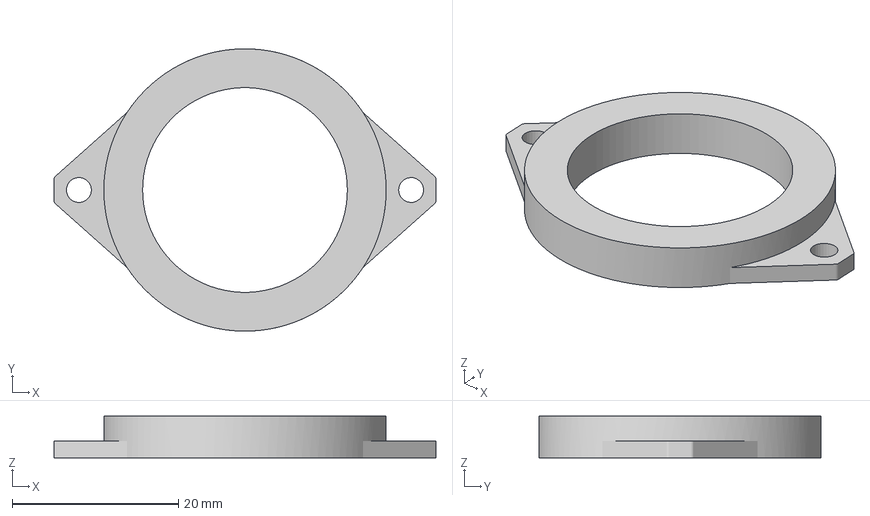
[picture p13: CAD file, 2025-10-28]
3D_models/Supports/Craazy wheel support.3mf
46.0 x 34.0 x 5.00 mm

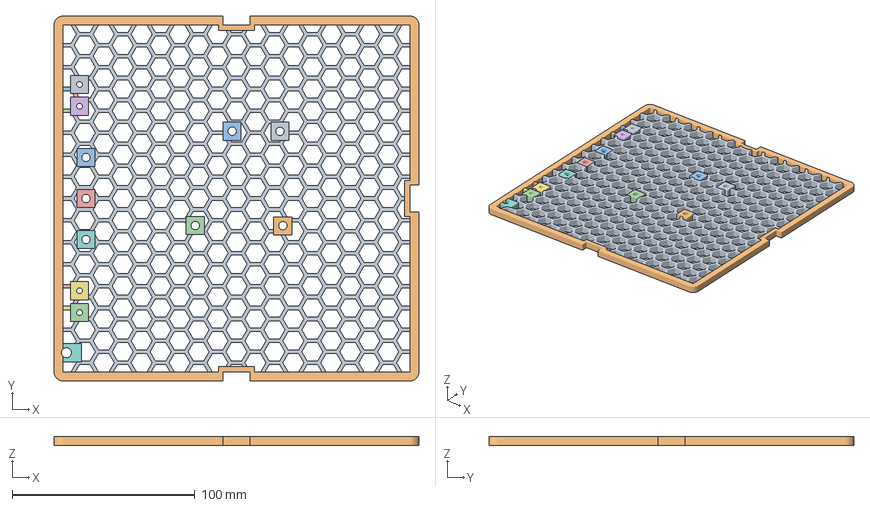
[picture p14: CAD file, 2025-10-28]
3D_models/Main structure/Roof Support.3mf
200.0 x 200.0 x 5.00 mm
Corps1
Corps11
Corps24
Corps25
Corps26
Corps27
Corps28
Corps29
Corps30
Corps31
Corps32
Corps33
Corps34
Corps35
Corps36
Corps37
Corps38
Corps6
Corps7
Corps8
Corps9

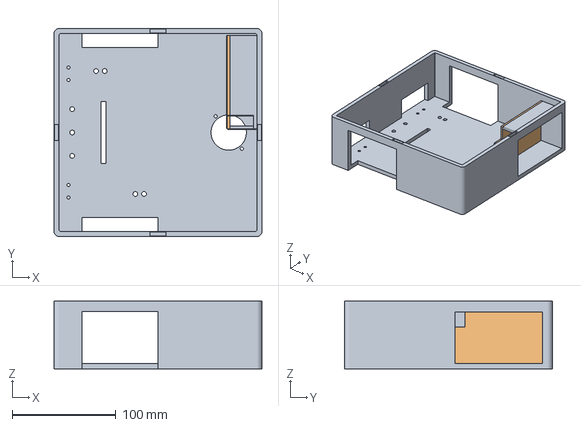
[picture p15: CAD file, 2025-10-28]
3D_models/Main structure/Motor section.3mf
200.0 x 200.0 x 65.0 mm
Corps1
Corps2

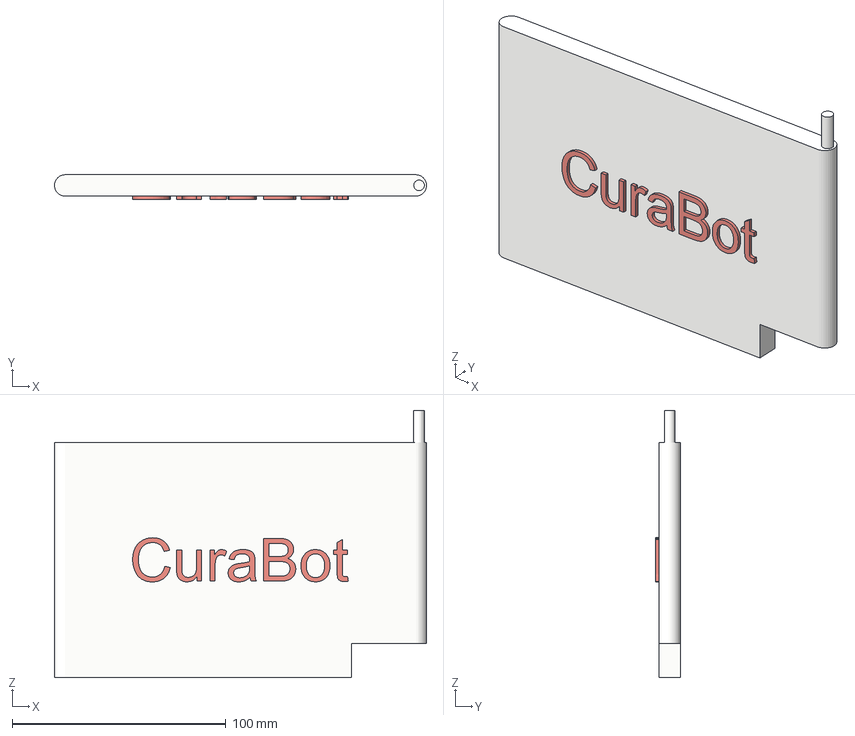
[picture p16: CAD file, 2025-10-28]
3D_models/Main structure/Door.3mf
174.0 x 11.5 x 125.0 mm
Corps1
Corps2
Corps3
Corps4
Corps5
Corps6
Corps7
Corps8

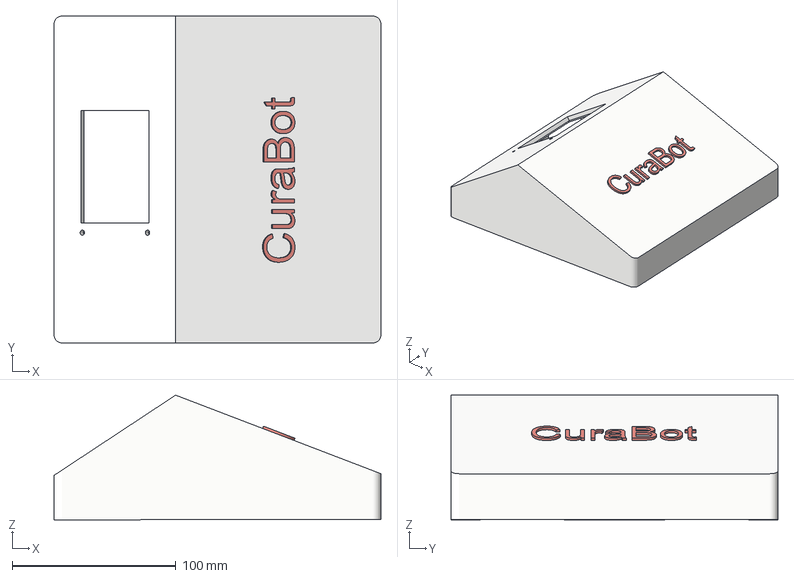
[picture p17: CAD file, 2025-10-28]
3D_models/Main structure/Roof.3mf
200.0 x 200.0 x 76.3 mm
Corps1
Corps10
Corps3
Corps4
Corps5
Corps6
Corps7
Corps8
Corps9

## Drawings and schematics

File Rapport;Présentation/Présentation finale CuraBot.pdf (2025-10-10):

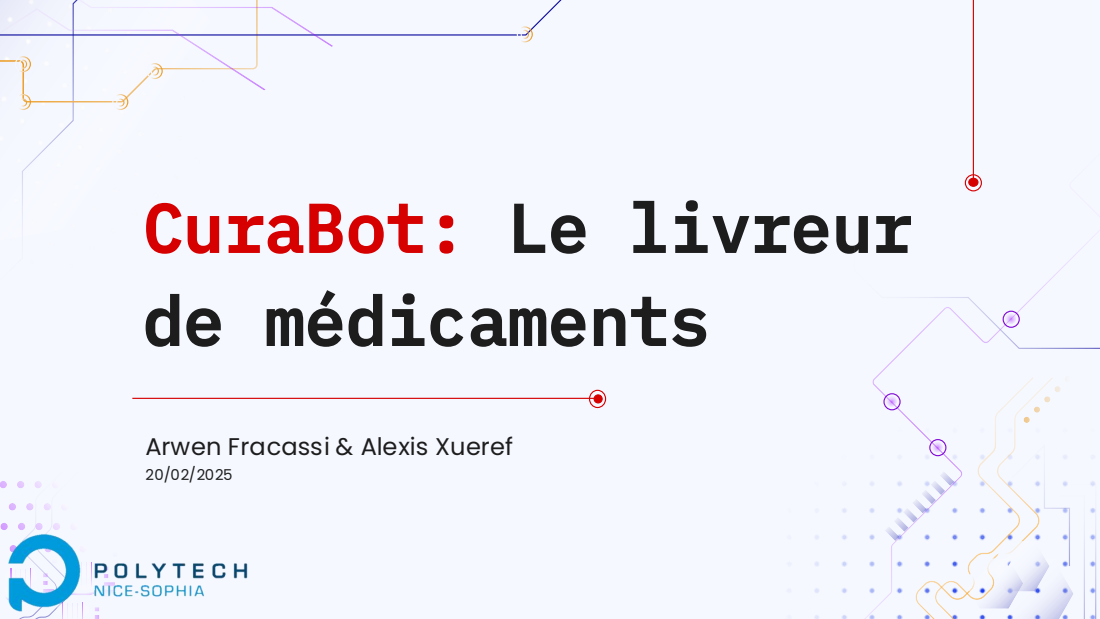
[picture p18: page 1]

CuraBot: Le livreur
de médicaments

Arwen Fracassi & Alexis Xueref

## 01 – Problématique & Objectif

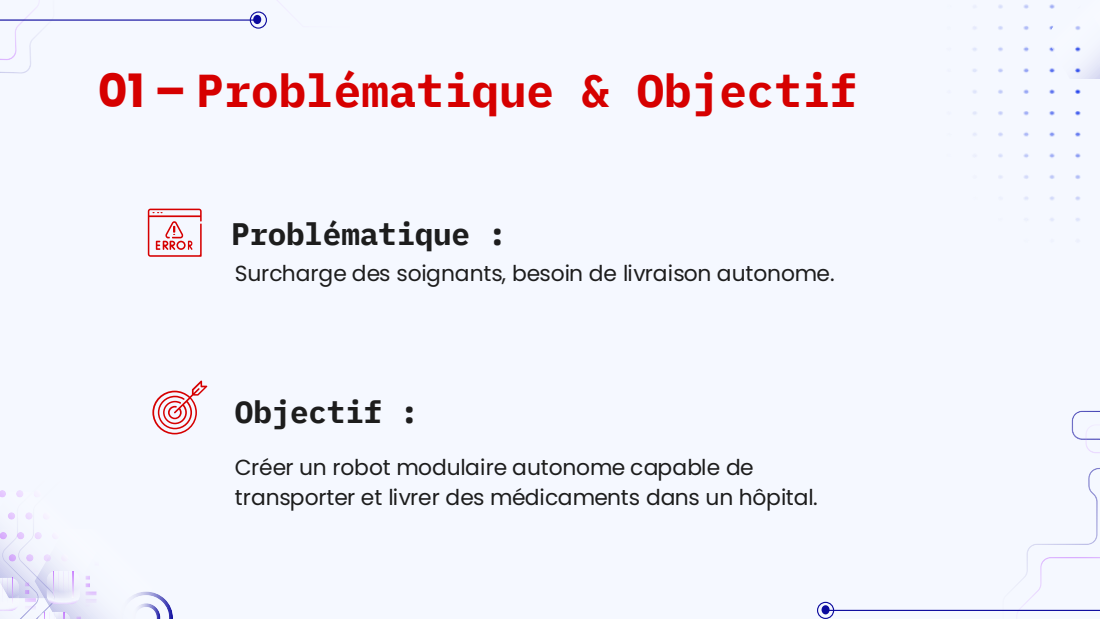
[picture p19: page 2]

Problématique :
Surcharge des soignants, besoin de livraison autonome.

Objectif :
Créer un robot modulaire autonome capable de
transporter et livrer des médicaments dans un hôpital.

## 02 – Vue d’ensemble du robot

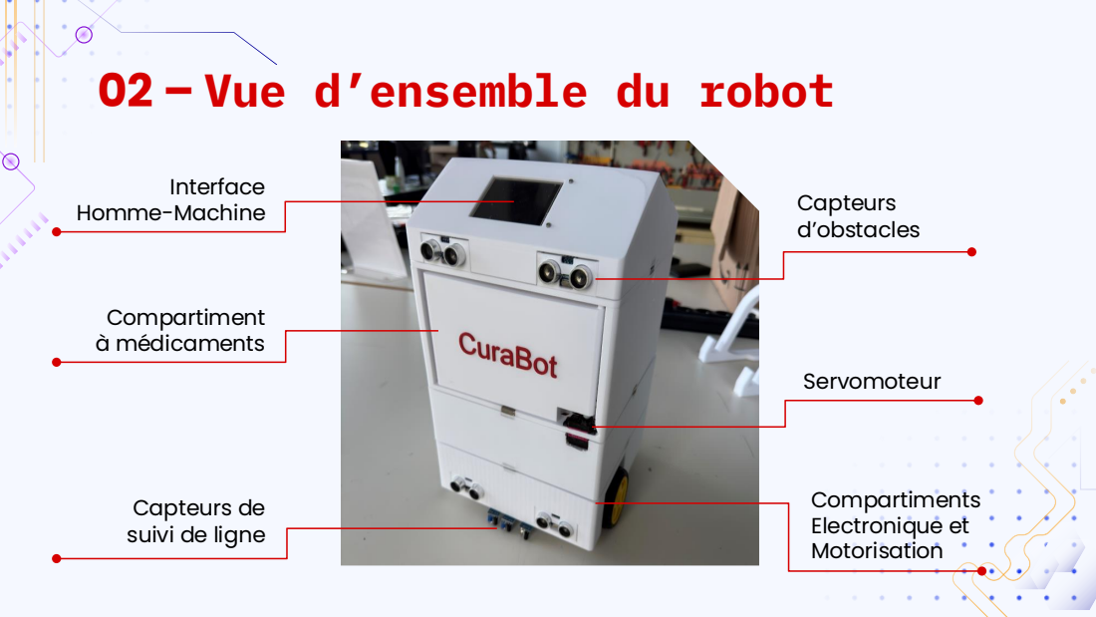
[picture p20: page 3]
Capteurs d’obstacles; Interface Homme-Machine; Compartiment à médicaments; Servomoteur; Compartiments Electronique et Motorisation

Capteurs de
suivi de ligne

## 03 – Conception et design

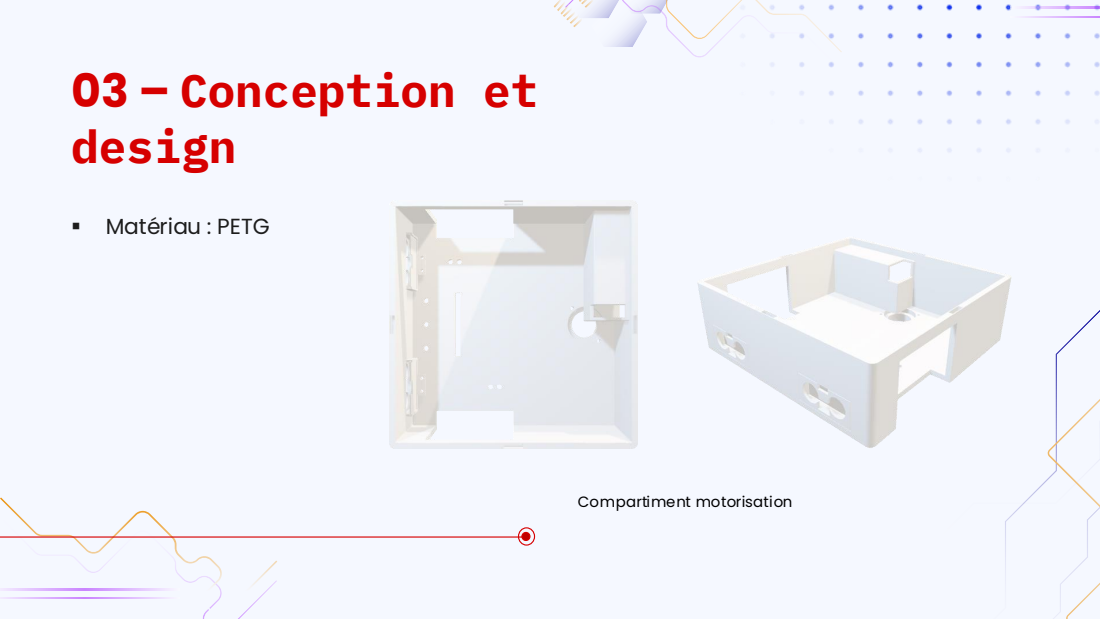
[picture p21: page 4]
▪ Matériau : PETG; Compartiment motorisation

## 03 – Conception et design

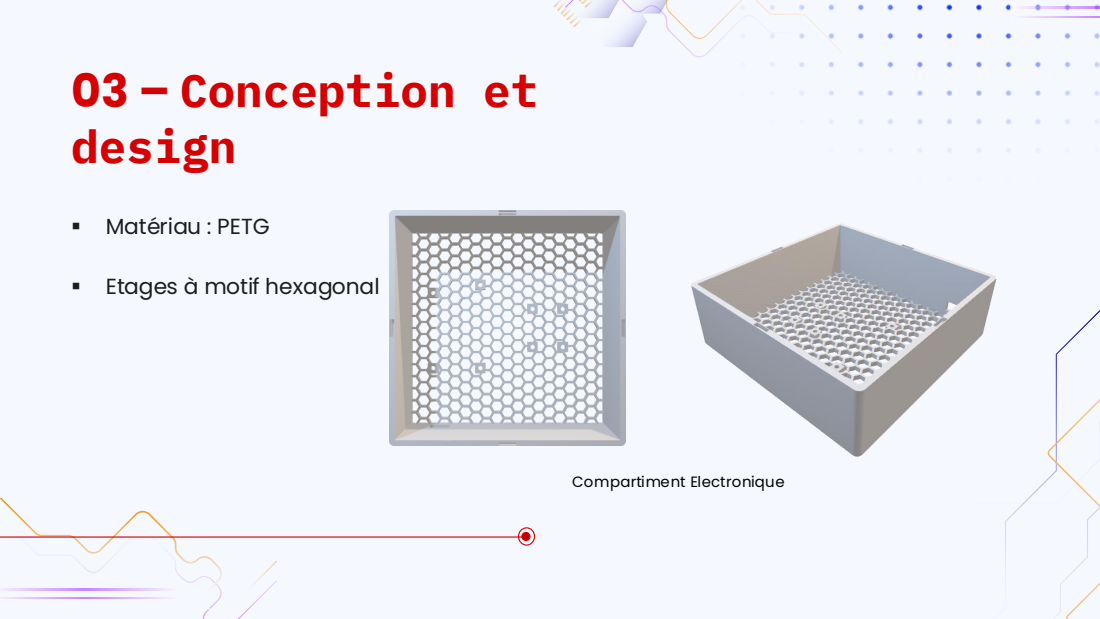
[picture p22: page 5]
▪ Matériau : PETG; Compartiment Electronique

▪ Etages à motif hexagonal

## 03 – Conception et design

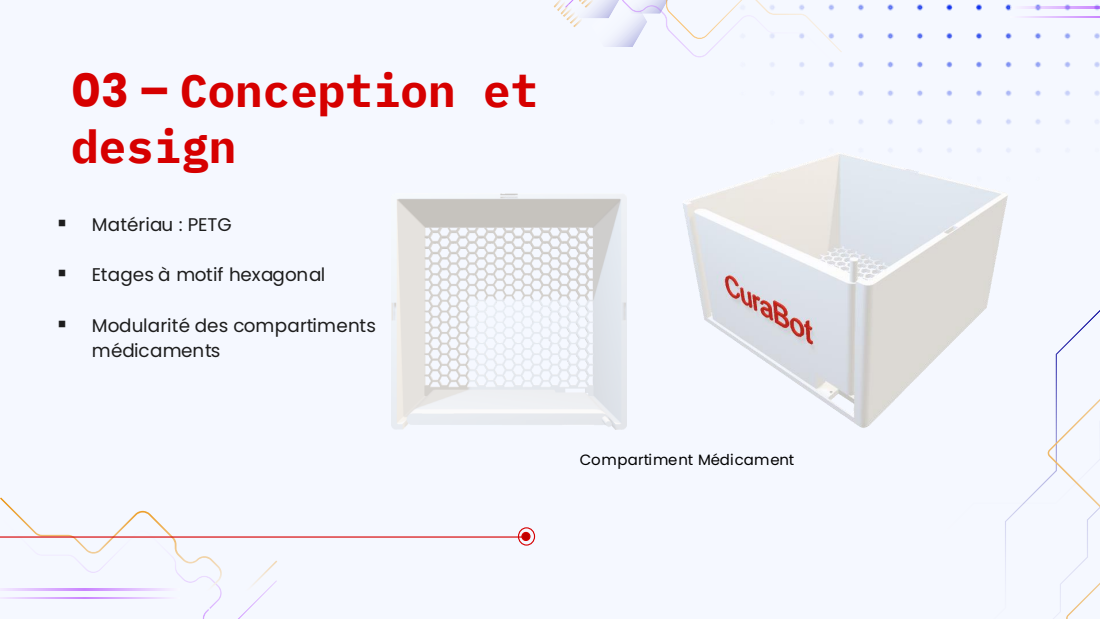
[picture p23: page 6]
▪ Matériau : PETG; Compartiment Médicament

▪ Etages à motif hexagonal

▪ Modularité des compartiments
médicaments

## 03 – Conception et design

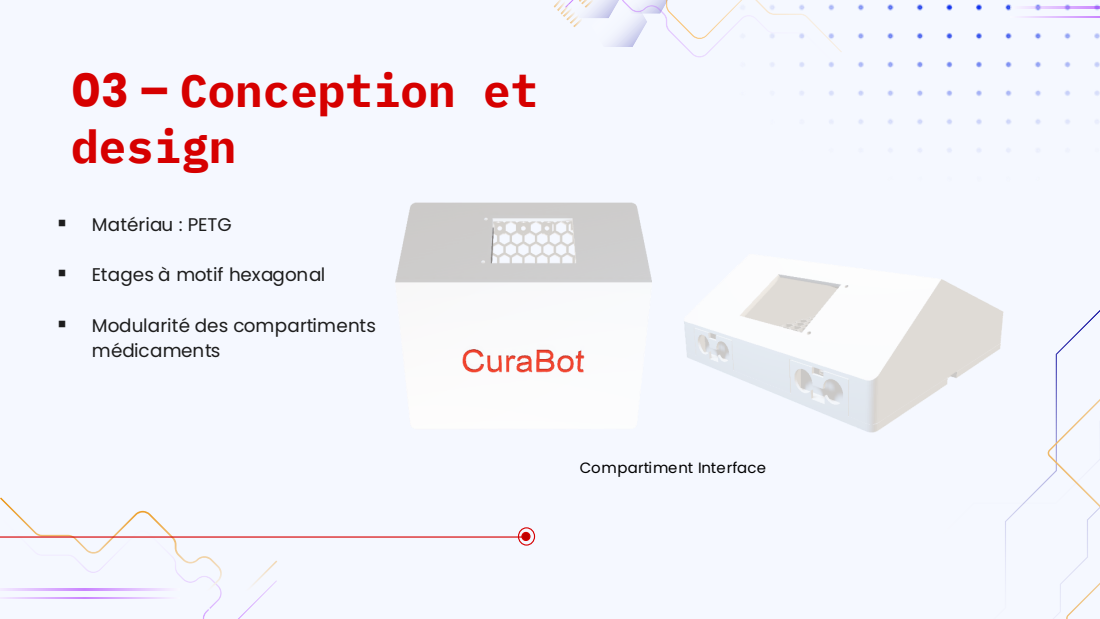
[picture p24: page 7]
▪ Matériau : PETG; Compartiment Interface

▪ Etages à motif hexagonal

▪ Modularité des compartiments
médicaments

## 04 – Système embarqué

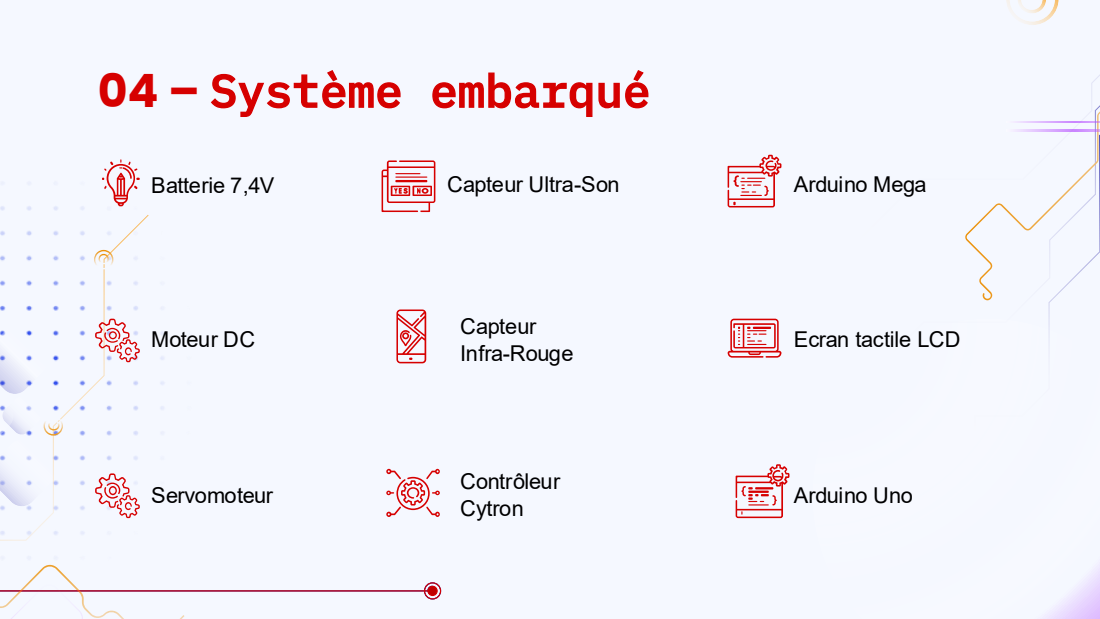
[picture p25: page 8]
Batterie 7,4V; Capteur Ultra-Son; Arduino Mega; Arduino Uno; Capteur; Infra-Rouge Moteur DC; Ecran tactile LCD; Servomoteur; Contrôleur; Cytron

## 05 – Programmation et capteurs

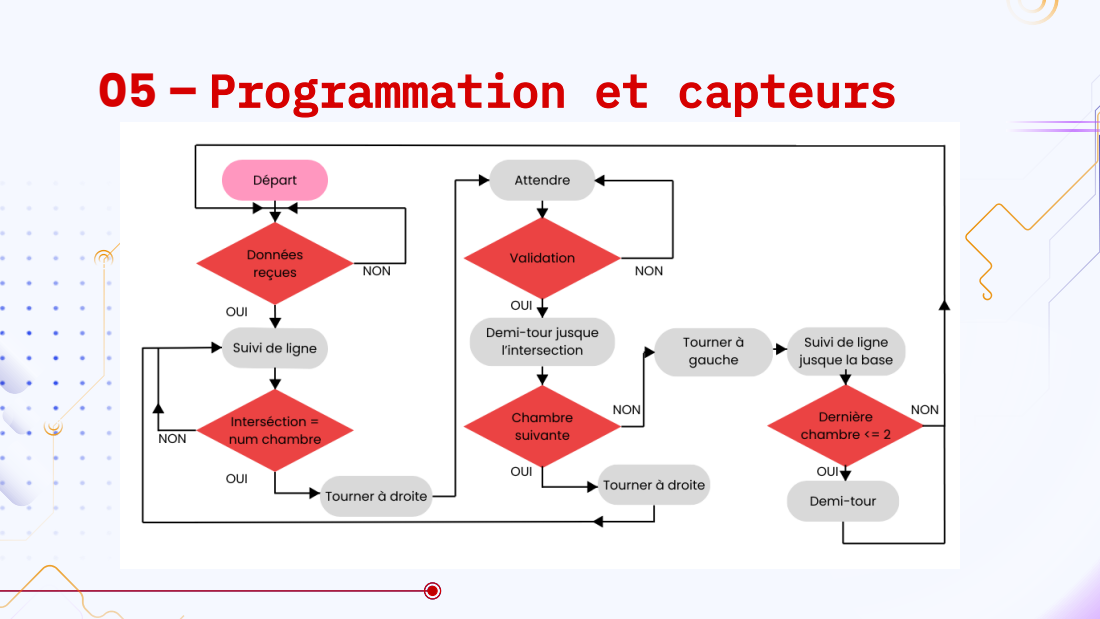
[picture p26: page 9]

## 06 – Démonstration de CuraBot

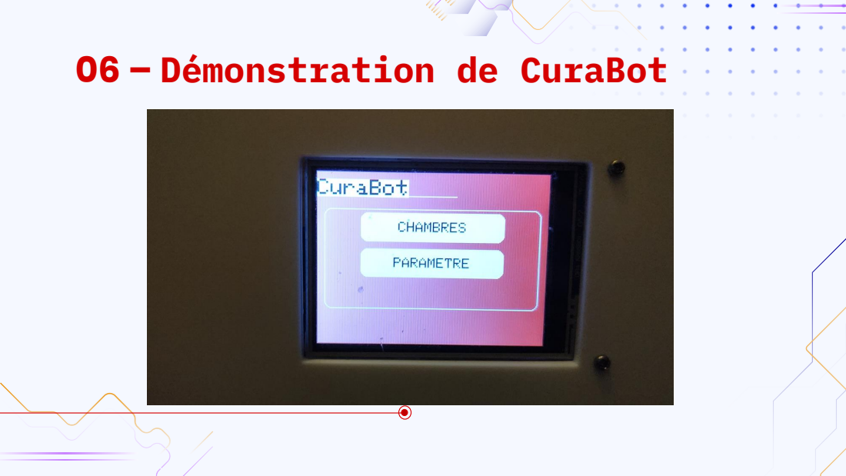
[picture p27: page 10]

## 07 – Bilan et améliorations

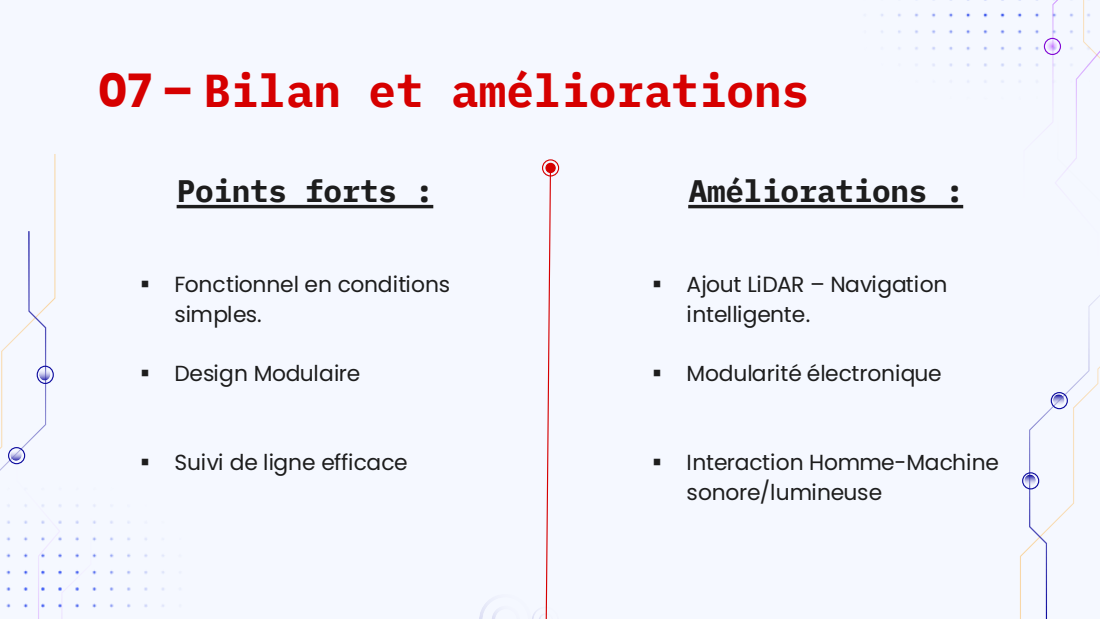
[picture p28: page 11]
Points forts :; ▪ Design Modulaire; Améliorations :; ▪ Modularité électronique

▪ Fonctionnel en conditions
simples.

▪ Ajout LiDAR – Navigation
intelligente.

▪ Suivi de ligne efficace

▪ Interaction Homme-Machine
sonore/lumineuse

## 08 – Conclusion

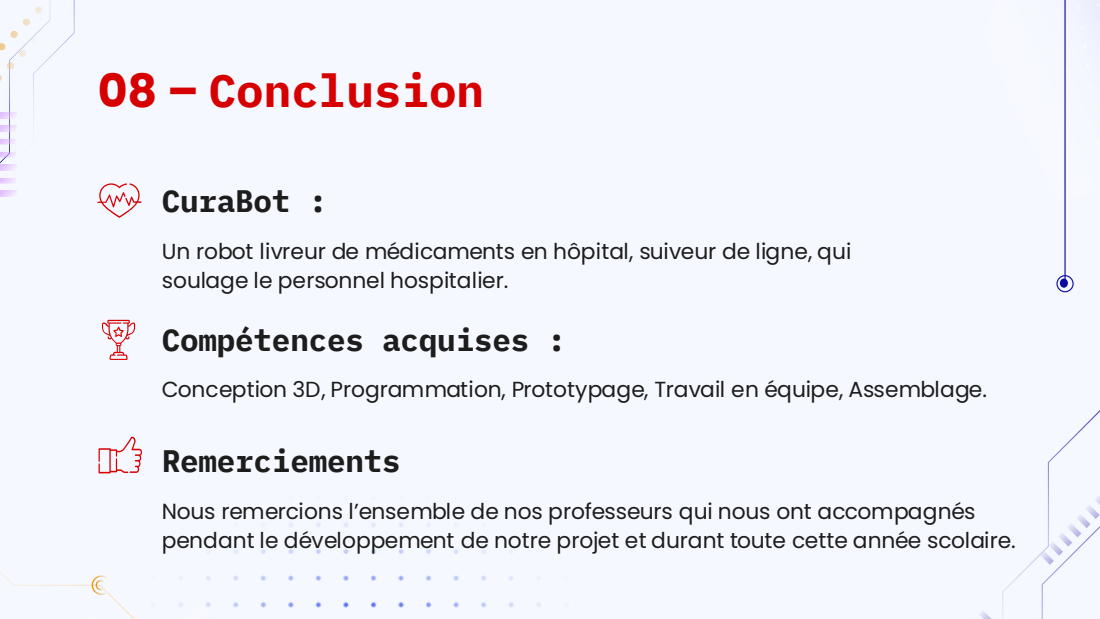
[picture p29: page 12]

CuraBot :
Un robot livreur de médicaments en hôpital, suiveur de ligne, qui
soulage le personnel hospitalier.

Compétences acquises :
Conception 3D, Programmation, Prototypage, Travail en équipe, Assemblage.

Remerciements
Nous remercions l’ensemble de nos professeurs qui nous ont accompagnés
pendant le développement de notre projet et durant toute cette année scolaire.

## 09 – Contacts


Coordonnées:
● Arwen Fracassi – arwen.fracassi@etu.unice.fr
● Alexis Xueref – alexis.xueref@etu.unice.fr

Lien dépôt Github :
● https://github.com/AlexisXueref/Curabot-final

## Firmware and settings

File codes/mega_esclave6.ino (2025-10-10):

//I2C SLAVE CODE
//I2C Communication between Two Arduino
//CircuitDigest
//Pramoth.T
#include <Wire.h>  //Library for I2C Communication functions
#include "CytronMotorDriver.h"
#include "Servo.h"

CytronMD motor1(PWM_PWM, 3, 9);    // PWM 1A = Pin 3, PWM 1B = Pin 9.
CytronMD motor2(PWM_PWM, 10, 11);  // PWM 2A = Pin 10, PWM 2B = Pin 11.

Servo servo;  // création de l'objet "servo"

#define IR_LEFT A9
#define IR_MIDDLE A11
#define IR_RIGHT A13
#define PIN_SERVO 8


const int trig1 = 48;
const int echo1 = 49;
float lecture_echo1 = 0;
float distance1;

const int trig2 = 52;
const int echo2 = 53;
float lecture_echo2 = 0;
float distance2;

const int trig3 = 37;
const int echo3 = 36;
float lecture_echo3 = 0;
float distance3;

int nb_intersections = 0;
int a = 0;

int chambre_a_livrer;
int SlaveReceived[] = { -1, 0, 0, 0, 0, 0, false };
int intersection;
int i = 0;
int ancienne_chambre = 0;

bool chambre_trouvee = false;
bool validation = false;
bool ok = false;

void robotStop() {
  motor1.setSpeed(0);  // Motor 1 stops.
  motor2.setSpeed(0);  // Motor 2 stops.
}

void robotForward() {
  motor1.setSpeed(-130);  // Motor 1 runs forward.
  motor2.setSpeed(-130);   // Motor 2 runs forward.
}

void robotReverse() {
  motor1.setSpeed(50);   // Motor 1 runs backward.
  motor2.setSpeed(50);  // Motor 2 runs backward.
}

void robotTurnLeft() {
  motor1.setSpeed(140);  // Motor 1 runs forward.
  motor2.setSpeed(-140);  // Motor 2 runs backward.
}

void robotTurnRight() {
  motor1.setSpeed(-140);  // Motor 1 runs backward.
  motor2.setSpeed(140);  // Motor 2 runs forward.
}

void robotDemiTour() {
  motor1.setSpeed(-145);  // Motor 1 runs backward.
  motor2.setSpeed(175);  // Motor 2 runs forward.
}

void suivi_ligne() {
  digitalWrite(trig1, HIGH);
    delayMicroseconds(10);
    digitalWrite(trig1, LOW);
    lecture_echo1 = pulseIn(echo1, HIGH);
    distance1 = lecture_echo1 * 0.017;
  //distance1 = 20;
  digitalWrite(trig2, HIGH);
  delayMicroseconds(10);
  digitalWrite(trig2, LOW);
  lecture_echo2 = pulseIn(echo2, HIGH);
  distance2 = lecture_echo2 * 0.017;

  digitalWrite(trig3, HIGH);
  delayMicroseconds(10);
  digitalWrite(trig3, LOW);
  lecture_echo3 = pulseIn(echo3, HIGH);
  distance3 = lecture_echo3 * 0.017;


  if ((distance1 < 10) || (distance2 < 10) || (distance3 < 10)) {
    Serial.println("capteur us passe");
    robotStop();
  } else {
    if (isOnWhite(IR_LEFT) && isOnBlack(IR_MIDDLE) && isOnWhite(IR_RIGHT)) {
      robotForward();
    }
    if (isOnBlack(IR_LEFT) && isOnWhite(IR_MIDDLE)) {
      robotTurnLeft();
    }
    if (isOnBlack(IR_RIGHT) && isOnWhite(IR_MIDDLE)) {
      robotTurnRight();
    }
    if (isOnBlack(IR_LEFT) && isOnBlack(IR_MIDDLE) && isOnBlack(IR_RIGHT)) {
      robotForward();
      nb_intersections = nb_intersections + 1;
      delay(250);
    }
    if (isOnWhite(IR_LEFT) && isOnWhite(IR_MIDDLE) && isOnWhite(IR_RIGHT)) {
      robotForward();
    }
    if (isOnBlack(IR_LEFT) && isOnBlack(IR_MIDDLE) && isOnWhite(IR_RIGHT)) {
      robotTurnLeft();
    }
    if (isOnBlack(IR_RIGHT) && isOnBlack(IR_MIDDLE) && isOnWhite(IR_LEFT)) {
      robotTurnRight();
    }
  }
}


bool isOnBlack(int sensor) {

  if (digitalRead(sensor) == HIGH) {
    return true;
  } else return false;
}


bool isOnWhite(int sensor) {
  if (digitalRead(sensor) == LOW) {
    return true;
  } else return false;
}


void service(int n) {
  Serial.println(n);
  robotStop();
  Serial.println("service");
  ancienne_chambre = SlaveReceived[n];
  SlaveReceived[n] = 0;
  //ouverture porte pendant que non validation
  while (validation == false) {
    servo.write(180);  // demande au servo de se déplacer à cette position
    delay(1000);       // attend 1000 ms entre changement de position

    validation = SlaveReceived[6];
    Serial.println("boucle");
    Serial.println(SlaveReceived[0]);
    Serial.println(SlaveReceived[1]);
    Serial.println(SlaveReceived[6]);
  }
  //quand validation: fermeture porte
  servo.write(90);
  delay(1000);
  //demi-tour
  robotDemiTour();
  delay(1200);
  while (isOnWhite(IR_LEFT)) {
    robotDemiTour();
  }
  nb_intersections = 0;
  //finir trajet
}


void setup() {
  Serial.begin(9600);  //Begins Serial Communication at 9600 baud rate

  servo.write(90);

  pinMode(IR_LEFT, INPUT);
  pinMode(IR_MIDDLE, INPUT);
  pinMode(IR_RIGHT, INPUT);

  pinMode(trig1, OUTPUT);
  pinMode(echo1, INPUT);
  pinMode(trig2, OUTPUT);
  pinMode(echo2, INPUT);

  servo.attach(PIN_SERVO);  // attache le servo au pin spécifié

  Wire.begin(8);                 //Begins I2C communication with Slave Address as 8 at pin (A4,A5)
  Wire.onReceive(receiveEvent);  //Function call when Slave receives value from master
  Wire.onRequest(requestEvent);  //Function call when Master request value from Slave
}


void loop(void) {

  Serial.println("Slave Received From Master:");  //Prints in Serial Monitor
  Serial.println(SlaveReceived[0]);
  chambre_a_livrer = SlaveReceived[0];

  while (SlaveReceived[i] != 0) {
    if (validation == false) {
      intersection = SlaveReceived[i];
      //Serial.println(intersection);
      //Serial.println(nb_intersections);
      Serial.print(digitalRead(IR_LEFT));
      Serial.print("  ");
      Serial.print(digitalRead(IR_MIDDLE));
      Serial.print("  ");
      Serial.println(digitalRead(IR_RIGHT));

      delay(500);

      while ((SlaveReceived[i] != -1) && (nb_intersections != (SlaveReceived[i] - ancienne_chambre))) {
        Serial.print("robot commence ");
        Serial.print(SlaveReceived[i]);
        intersection = SlaveReceived[i];
        Serial.println(intersection);

        Serial.println(SlaveReceived[0]);
        Serial.println(SlaveReceived[1]);
        Serial.println(SlaveReceived[2]);
        Serial.println(SlaveReceived[6]);

        suivi_ligne();
      }

      robotStop();
      delay(1000);

      if ((nb_intersections == SlaveReceived[i] - ancienne_chambre) && chambre_trouvee == false) {
        chambre_trouvee = true;
        robotTurnRight();
        delay(600);
        while (isOnWhite(IR_LEFT)) {
        }
        robotStop();
        nb_intersections = 0;
      }

      while ((chambre_trouvee == true) && (nb_intersections != 1)) {
        suivi_ligne();
      }

      while ((chambre_trouvee == true) && (nb_intersections == 1)) {
        service(i);
        nb_intersections = 0;
      }
    } else if (validation == true) {
      Serial.println("commande recuperee");
      robotStop();

      while ((ok == false) && (nb_intersections != 1)) {
        suivi_ligne();
      }

      if ((ok == false) && nb_intersections == 1) {
        robotStop();
        delay(1000);
        if (SlaveReceived[i + 1] == 0) {
          if (intersection <= 2) {
            robotTurnLeft();
            delay(600);
            while (isOnWhite(IR_MIDDLE)) {
              robotTurnLeft();
            }
            robotStop();
            delay(100);
            ok = true;
            nb_intersections = 0;

            while ((ok == true) && (nb_intersections != intersection)) {

              suivi_ligne();
            }

            robotStop();
            delay(1000);
            robotDemiTour();
            delay(1000);
            while (isOnWhite(IR_MIDDLE)) {
              robotDemiTour();
            }
            robotStop();
            delay(100);
          } else {
            robotTurnRight();
            delay(600);
            while (isOnWhite(IR_LEFT)) {
              robotTurnRight();
            }
            robotStop();
            delay(100);
            ok = true;
            nb_intersections = 0;

            while ((ok == true) && (nb_intersections != 6 - intersection)) {

              suivi_ligne();
            }

            robotStop();
          }
          validation = false;
          nb_intersections = 0;
          chambre_trouvee = false;
          ok = false;
          SlaveReceived[0] = -1;
          ancienne_chambre = 0;
          i = 0;

        } else {
          robotTurnRight();
          delay(600);
          while (isOnWhite(IR_LEFT)) {
            robotTurnRight();
          }
          robotStop();
          delay(200);
          i += 1;
          nb_intersections = 0;
          SlaveReceived[6] = false;
          chambre_trouvee = false;
          ok = false;
          validation = false;
        }
      }
    }
  }
}
void receiveEvent(int howMany)  //This Function is called when Slave receives value from master
{
  Wire.readBytes((uint8_t*)&SlaveReceived, 14);
}
void requestEvent()  //This Function is called when Master wants value from slave
{
  int potvalue = 5;      // Reads analog value from POT (0-5V)
                         // Convert potvalue digital value (0 to 1023) to (0 to 127)
  Wire.write(potvalue);  // sends one byte converted POT value to master
}

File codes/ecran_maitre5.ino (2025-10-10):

#include <Wire.h>  //Library for I2C Communication functions
#include <Adafruit_GFX.h>
#include <MCUFRIEND_kbv.h>
MCUFRIEND_kbv tft;
#include <TouchScreen.h>

#include <Fonts/FreeSans9pt7b.h>
#include <Fonts/FreeSans12pt7b.h>
#include <Fonts/FreeSerif12pt7b.h>
#include <FreeDefaultFonts.h>

#define MINPRESSURE 200
#define MAXPRESSURE 1000


//3.5 Calibration
const int XP = 8, XM = A2, YP = A3, YM = 9;  //320x480 ID=0x9486
const int TS_LEFT = 944, TS_RT = 101, TS_TOP = 73, TS_BOT = 907;


TouchScreen ts = TouchScreen(XP, YP, XM, YM, 300);
TSPoint p;

Adafruit_GFX_Button on_btn, off_btn, page1_btn, page2_btn, page3_btn;
Adafruit_GFX_Button ok_btn, cncl_btn, plus_btn, minus_btn;
Adafruit_GFX_Button menu_btn, info_btn, back_btn;

int pixel_x, pixel_y;  //Touch_getXY() updates global vars

// Button calibration
int margin = 5;
int btnWidth = 100;
int btnHeight = 40;
int btnY = 200;

// Software variable
bool enable_nuit = false;
int parameter = 50, old_parameter = 50;

long temp0 = 60;
long temp1 = 25.5;
long temp2 = 40;
long temp3 = 35.6;


#define BLACK 0x0000
#define GREY 0x5555
#define BLUE 0x001F
#define RED 0xF800
#define GREEN 0x07E0
#define DARKGREEN 0x05C0
#define CYAN 0x07FF
#define MAGENTA 0xF81F
#define YELLOW 0xFFE0
#define GOLD 0xDDC0
#define WHITE 0xFFFF


int donnees[] = { 0, 0, 0, 0, 0, 0, false };
int chambre = donnees[0];
bool validation = donnees[6];
int choix_chambre = 0;
int i = 0;


enum pageId {
  MENU,
  CHAMBRES,
  VALIDATION,
  PARAMETRE,
  SERVICE
};

unsigned int currentPage = MENU, oldPage = -1;


void setup() {
  Serial.begin(9600);  //Begins Serial Communication at 9600 baud rate
  tft.reset();
  tft.begin(0x9341);  //Démarrage du shield
  tft.setRotation(1);

  currentPage = MENU;  // Indicates that we are at Home Screen
  Serial.println("Home Page");
  Wire.beginTransmission(8);  // start transmit to slave arduino (8)
  Wire.begin();               //Begins I2C communication at pin (A4,A5)
}




bool down;
void loop() {

  switch (currentPage) {
    case MENU:  //Menu page
      if (currentPage != oldPage) drawMenuScreen();
      page1_btn.press(down && page1_btn.contains(pixel_x, pixel_y));
      page2_btn.press(down && page2_btn.contains(pixel_x, pixel_y));

      if (page1_btn.justReleased())
        page1_btn.drawButton();

      if (page1_btn.justPressed()) {
        page1_btn.drawButton(true);
        currentPage = CHAMBRES;
        for (int  i= 0; i < 6; i++) {
          donnees[i] = 0;
        }
        choix_chambre = 0;
      }

      if (page2_btn.justReleased())
        page2_btn.drawButton();

      if (page2_btn.justPressed()) {
        page2_btn.drawButton(true);
        currentPage = PARAMETRE;
      }

      break;

    case CHAMBRES:
      if (currentPage != oldPage) drawChambresScreen();
      updateChambre();
      menu_btn.press(down && menu_btn.contains(pixel_x, pixel_y));
      ok_btn.press(down && ok_btn.contains(pixel_x, pixel_y));



      if (menu_btn.justReleased())
        menu_btn.drawButton();
      if (ok_btn.justReleased())
        ok_btn.drawButton();
      if (menu_btn.justPressed()) {
        menu_btn.drawButton(true);
        currentPage = MENU;
      } else if (ok_btn.justPressed()) {
        ok_btn.drawButton(true);
        Serial.println(F("Valider"));
        delay(1000);
        currentPage = VALIDATION;
        Serial.println(currentPage);
        Serial.println(currentPage);
        Serial.println(chambre);

      } else {
        TSPoint p = ts.getPoint();

        if (p.z > ts.pressureThreshhold) {

          if ((170 < p.x) && (p.x < 370) && (100 < p.y) && (p.y < 250)) {
            donnees[choix_chambre] = 1;
            choix_chambre = choix_chambre + 1;
          } else if ((170 < p.x) && (p.x < 370) && (305 < p.y) && (p.y < 455)) {
            donnees[choix_chambre] = 2;
            choix_chambre = choix_chambre + 1;
          } else if ((170 < p.x) && (p.x < 370) && (515 < p.y) && (p.y < 670)) {
            donnees[choix_chambre] = 3;
            choix_chambre = choix_chambre + 1;
          } else if ((490 < p.x) && (p.x < 700) && (100 < p.y) && (p.y < 250)) {
            donnees[choix_chambre] = 4;
            choix_chambre = choix_chambre + 1;
          } else if ((520 < p.x) && (p.x < 730) && (305 < p.y) && (p.y < 455)) {
            donnees[choix_chambre] = 5;
            choix_chambre = choix_chambre + 1;
          } else if ((520 < p.x) && (p.x < 730) && (515 < p.y) && (p.y < 670)) {
            donnees[choix_chambre] = 0;
            choix_chambre = choix_chambre + 1;
          } else if ((770 < p.x) && (p.x < 900) && (370 < p.y) && (p.y < 470)) {
            choix_chambre = choix_chambre - 1;
          } else if ((770 < p.x) && (p.x < 900) && (500 < p.y) && (p.y < 600)) {
            choix_chambre = choix_chambre + 1;
          } else {
            chambre = 0;
          }
        }
        delay(100);
      }

      break;

    case VALIDATION:  //Validation page
      if (currentPage != oldPage) drawValidationScreen();
      delay(2000);
      currentPage = SERVICE;
      robotStart(chambre);


      break;

    case SERVICE:  //Validation page
      if (currentPage != oldPage) drawServiceScreen();
      menu_btn.press(down && menu_btn.contains(pixel_x, pixel_y));

      if (menu_btn.justReleased())
        menu_btn.drawButton();


      if (menu_btn.justPressed()) {
        menu_btn.drawButton(true);
        Validation();
        //currentPage = MENU;
      }

      break;

    case PARAMETRE:  
      if (currentPage != oldPage) drawParametreScreen();
      menu_btn.press(down && menu_btn.contains(pixel_x, pixel_y));

      if (menu_btn.justReleased())
        menu_btn.drawButton();

      if (menu_btn.justPressed()) {
        menu_btn.drawButton(true);
        currentPage = MENU;
      }

      break;
  }
  if (oldPage == currentPage) {
    down = Touch_getXY();
  } else {
    down = false;
  }
}





/// PAAMETRAGE DES DIFFERANTES PAGES ///
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

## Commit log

2025-10-28 Added all the 3D structure files
    [Door.3mf, Elec section.3mf, Medicine section.3mf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]
2025-10-28 Added all the supports
    [Craazy wheel support.3mf, Support Ultrasound sensor.3mf]
